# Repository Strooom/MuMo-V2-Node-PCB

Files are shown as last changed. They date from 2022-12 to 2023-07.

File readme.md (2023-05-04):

# Lora-based environmental monitor
* intended for monitoring collection items in musea. Other applications are possible but the unit is currently designed for indoor use only
* monitors temperature, relative humidity, VOC gasses, barometric pressure, light intensity and others
	- BME680 and TSL25911 sensors are built in, other can be added through I2C or UART
* runs on a single cell LiFePO4 battery. Battery-charger from USB-C port included
* Wio-E5 LoRa module from www.seeedstudio.com. This contains an STM32WLE processor combined with Semtech SX126X radio. The firmware runs directly on the STM32. More info on this Wio-E5 :  https://www.seeedstudio.com/LoRa-E5-Wireless-Module-p-4745.html
* 128 KByte of onboard EEPROM allows to buffer sensor-readings when network is unavailable.
* ePaper display allows to identify the device, and read status from the display, while still being ultra low power.

The related firmware for this device can be found in https://github.com/Strooom/MuMo-v2-Node-SW

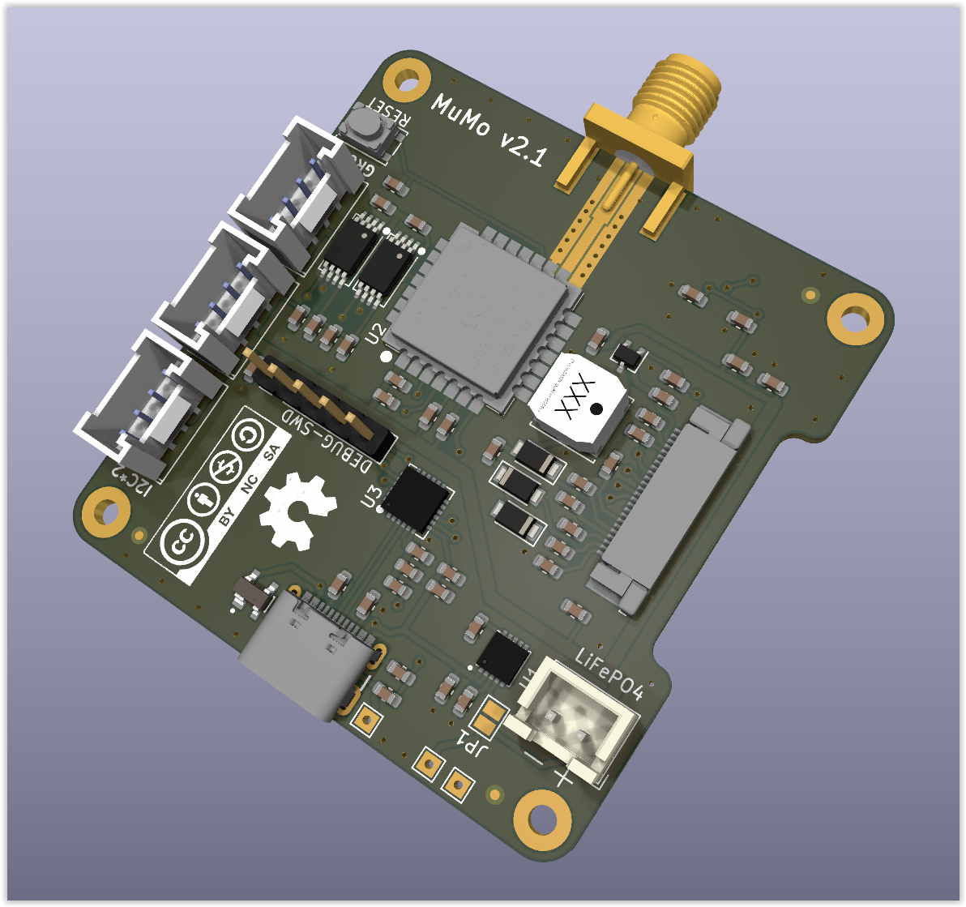
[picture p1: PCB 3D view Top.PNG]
PCB Render Top view


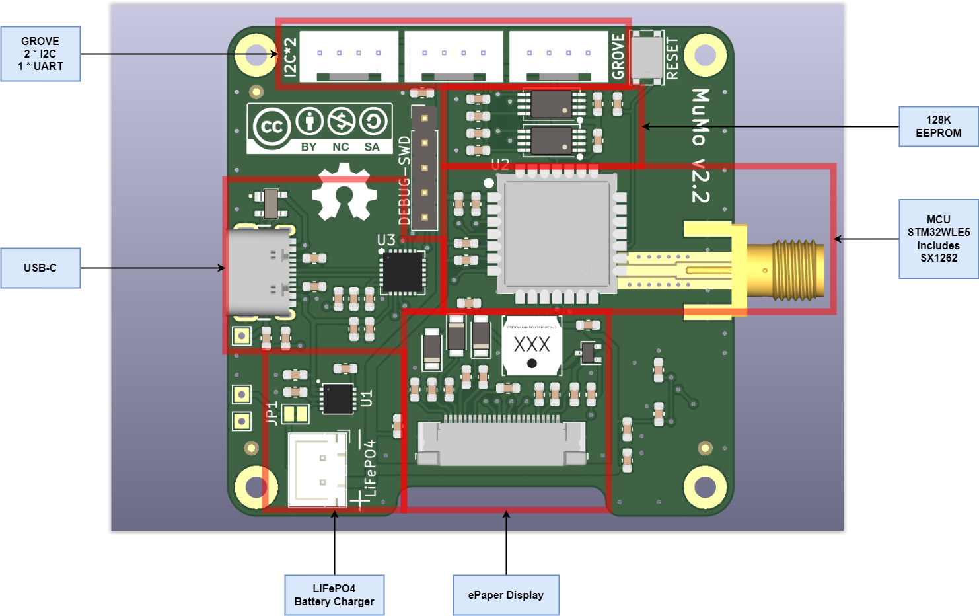
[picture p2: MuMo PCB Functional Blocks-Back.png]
PCB Backside Functional Blocks


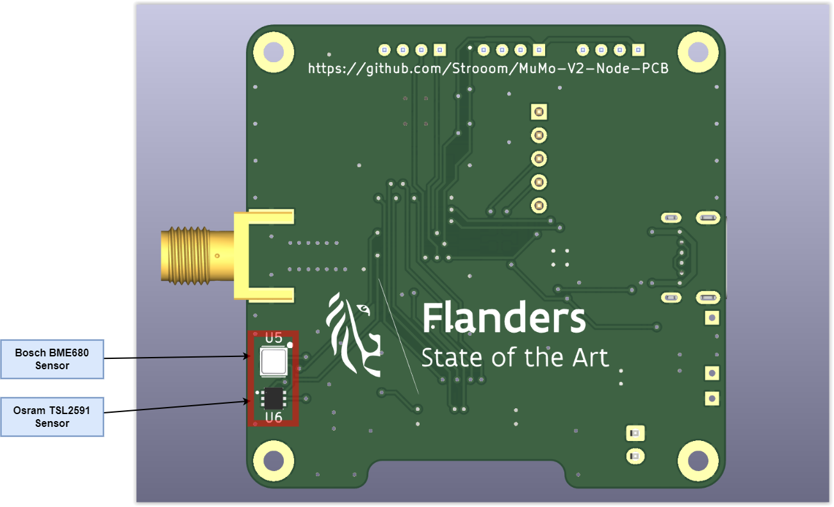
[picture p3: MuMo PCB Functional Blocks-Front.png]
PCB Frontside Functional Blocks


More info can be found in the Wiki : 
https://github.com/Strooom/MuMo-V2-Node-PCB/wiki

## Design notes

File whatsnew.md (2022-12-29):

# Improvements MuMo V2 HW vs V1

1. has a USB-C connector (io. USB-micro) which is the new EU standard for charging devices
2. has a USB-UART chip (CN2102N) so the USB connection with any PC-host will stay alive. V1 loses the connection after going into low-power-sleep
3. has a built-in charger for LiFePO4 battery. The MCU is aware of external USB-power and can adjust its program flow on it.
4. has the 2 most common sensors (BME68x and TSL2591/TSL2561) built in, and still 2 Grove-I2C and 1 Grove-UART connector, for extending to additional sensors
5. runs the SW on the embedded STM32WLE5 MCU, reducing size, power and cost. V1 used an ATSAMD21 MCU which is currently out of stock.
6. has EEPROM on the PCB to store:
    - all network settings. V1 requires a unique firmware per device. V2 firmware will be standard and use unique settings from EEPROM
    - all data until confirmed by the cloud application
    - V1 stored settings in the MCU flash, but this flash has a limited number of erase/write cycles (10K io. 10M)
7. has a better antenna connector (SMA), resulting in better radio signal, lower power, more bandwidth, etc. Different antennas exist for this connector
8. has an ePaper display. This display will improve the human interaction with the device:
    - show the device's identity
    - show the battery level
    - show charging progress
    - show network connectivity
    - show any kind of alarms, measurement values, etc
9. can be programmed and debugger via SWD connector with standard ST-LINK - Programming via USB is also foreseen 

# Improvements Descoped for this iteration, candidates for a next iteration
* could use a PCB antenna. This would require to also add an RF switch.

# Removed from the design
* Real-time clock (RTC) : I did no longer see the benefits vs the built-in RTC in the STM32, given that we can regularly sync its clock from the LoRa network.

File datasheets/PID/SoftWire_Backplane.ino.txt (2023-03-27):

// *****************************************************
//
// V1.0,          Original version of SoftI2C code ... works OK but basic
// V2.0, 08/02/17 Cleaned up the code from V.1.0 - it works but was messy
// V2.1, 17/02/17 Takes Input from Serial Console for live re-configuration
//                Also counts uSecs between measures rather than ms accumulateddevice manager
// V3.0, 21/02/17 Added the RTC module, RTC & ASIC Temperature Monitoring.
// V4.0  01/05/19 DD Take over code base and rewrite
//
String Revision_Info = "Backplane V4.0 With Serial I/P & Temp";

// ******************************************************
// This program uses the Soft I2C library because The standard Wire library does
// not work with  the I2C protocol. Soft wire I2C library is available from:
// https://github.com/felias-fogg/SoftI2CMaster
// NB setClock() prototype needs to be commented out in line 56 of file SoftWire.h
// to remove compiler warning.
// 
// Pinout of Breakout Board header (PYB-266)
// ================================================
//                               /----+
// Vdd 3.3V MAX, NOT 5V       1 | o o | 2  Unassigned
// SCL (12C)Digital I/O       3 | o o | 4  SDA (12C)Digital I/O
// CS needs start-up sequence 5  ]o o | 6  INT (Optional)
// SYNC (Optional)            7 | o o | 8  CLK (Optional)
// Unassigned                 9 | o o | 10 Gnd
//                              +-----+
//
// Sensor to MCU interface board Pinout
// =====================================================
//   PYB-269 Left           Nano        PYB-269 Right
//  ----------------------  ----------- -------------------------
//  Rev B,diff Rev A        Left  Right Rev A         Rev B,diff
//  ---------  -----------  ----  ----- --------      -----------
//  N/C        INT_Sensor_2 TX1   VIN   VIN 
//  N/C        INT_Sensor_3 RX0   GND   GND all sensors
//             N/C          RST   RST   N/C
//             N/C          GND   5.0v  N/C
//             BT_2         D2    A7    INT_Sensor_4  N/C
//             Emit_Sync    D3    A6    BT_5          INT_Sensor_4
//             SDA          D4    A5    BT_4          INT_Sensor_3
//             SCL          D5    A4    BT_3          INT_Sensor_2
//             CS_1         D6    A3    INT_Sensor_1
//             Sync_microC  D7    A2    N/C
//             CLK_microC   D8    A1    LED_Ready
//             BT_0         D9    A0    LED_Running
//             BT_1         D10   REF   N/C
//             CS_2         D11   3.3v  VDD all sensors
//             CS_3         D12   D13   CS_4
//
// ******************************************************
// The default Address for the SMD device is 0x65
// this is shifted 1 bit to 11001010b; LSB =0, Wr =1, Rd 
//
// There are 5 24-bit A-D's (Channels 00 - 04)
// On single pixel Sensor, data on Channel 2
// On 2 x 2 pixel Sensor, data on Channel 1-4
//
// You can also define the following I2C constants
// - I2C_FASTMODE = 1, I2C bus up to 400 kHz
// - I2C_SLOWMODE = 1, I2C bus up to 25 kHz 
// Table of I2C bus speed in kbit/sec:
// CPU clock:           1MHz   2MHz    4MHz   8MHz   16MHz   20MHz
// Fast I2C mode          40     80     150    300     400     400
// Standard I2C mode      40     80     100    100     100     100
// Slow I2C mode          25     25      25     25      25      25  

//#define DEBUG                // uncomment to switch on Debug messages
#define I2C_FASTMODE 1
//#define eP_i2c  0x65        // Sensor I2C default address
byte eP_i2c = 0x65;           // Sensor I2C default address

#include "Sensor.h"               // Include Sensor Header
//#include <Wire.h>
#include <SoftWire.h>             // Assembly is in "softI2CMaster.h", included by SoftWire.h

// Global Variables
byte eP_FIFO[EP_FIFO_SZ+1] = {0,0,0,0,0,0,0,0,0,0,0,0,0,0,0,0,0,0}; // FIFO AND I2C comms buffers 
byte eP_STATUS = 0xFF;

unsigned long time_1;             // Timing Monitoring counters
unsigned long time_2;

// Channel Data & counters
byte eP_Clk_Div = 0;
byte eP_Pixel   = 1;

byte temp_on; // flag to indicate if channel 0 is set as a temp sensor, or

// General Variables
//byte error;
byte CPU_divider ;
//float Seconds_Passed; // not used
String keyboard_buffer;

SoftWire Wire = SoftWire();         // Create the Softwire Instance

/*******************************************************************************
 * Simple LED control macros
 *******************************************************************************/
#define RUN_LED_ON   digitalWrite(EP_LED_RUN, LOW)
#define RUN_LED_OFF  digitalWrite(EP_LED_RUN, HIGH)
#define RDY_LED_ON   digitalWrite(EP_LED_RDY, LOW)
#define RDY_LED_OFF  digitalWrite(EP_LED_RDY, HIGH)

// The Sensor CS is a 3V input and the Arduino Nano o/ps are a 5V o/p,
// so to minimise the strain on the Sesnor, the CS line is only an o/p
// when driving the line low. To o/p a high, the CP o/p is switched to
// an i/p, with internal pull up 20k resistor, wich can supply
// (5V-3V)/20k= 0.1 mA. The ESD clamping dione can pass 100mA max, so 
// the clamping diode can clamp the i/p CS line with ease.
#define EZP_DSEL(CS)  digitalWrite((CS),LOW);\
                      pinMode ((CS), OUTPUT);\
                      digitalWrite ((CS),LOW);
                
#define EZP_SEL(CS) digitalWrite ((CS), 0);\
                    pinMode ((CS), INPUT_PULLUP);
//                  pinMode((CS),     OUTPUT); 
//                  digitalWrite ((CS), HIGH);
//  PORTD |=  _BV(PD6);                     // toggle CS_1,D6/ PD6, 38x speed of Arduino Code
//  PORTD &= ~_BV(PD6);                     // Arduino toggle is 4.75us, True C toggle is 0.125us
//  PORTD |=  _BV(PD6);

/********************************************************************************
 * Setup function
 ********************************************************************************/
void setup(void) {
  time_1= micros();                       // Start the timer counter
  temp_on= 1;
  // Configure the Arduino I/O to talk to the Sensor Breakout Board Backplane
  pinMode(EP_LED_RUN, OUTPUT);            // Set the "Running" LED
  pinMode(EP_LED_RDY, OUTPUT);
//  pinMode(EP_CS1,     OUTPUT);            // Chip Selects for the 4 possible Sensors
//  pinMode(EP_CS2,     OUTPUT);            //
//  pinMode(EP_CS3,     OUTPUT);            // 
//  pinMode(EP_CS4,     OUTPUT);            // 
  pinMode(A2,         OUTPUT);            // Softserial port Tx line
  
  pinMode(EP_INT1,    INPUT_PULLUP);      // Interrupt (INT) is on A3
    
//  digitalWrite(EP_CS1, HIGH);             // Ensable all Chip Selects
//  digitalWrite(EP_CS2, HIGH);             // 
//  digitalWrite(EP_CS3, HIGH);             // 
//  digitalWrite(EP_CS4, HIGH);             // 
//    while(1){}
EZP_SEL(EP_CS1)
EZP_DSEL(EP_CS1)
EZP_SEL(EP_CS1)
EZP_SEL(EP_CS2)
EZP_SEL(EP_CS3)
EZP_SEL(EP_CS4)

  Wire.begin();                           // Start up the Soft i2c bus

  RUN_LED_OFF;
  RDY_LED_OFF;

  // Chip Sellect Start-up Scenario - CS toggling.
  // The CS line controls both power and reset at the same time, 
  // then some of the internal register will not be reset properly. 
  // The CS sequence should be:
  //  - CS high, wait at least 5us for 1.8v regulator to come up
  //  - CS low, wait 0.10us - 10us. The low pulse can be as short as 0.05us. 
  //    If CS low >100us (~155us) the power supply will drop. 
  //    Then restart the sequence again.
  //  - CS high to complete the reset.

  time_2 = micros();
  while(micros() - time_2 < 10){}  // Force 10 us Hi to ensure stable start - Have gone as low as 5us and still OK
  
  // Force the smallest possible Low (Lo/Hi on Chip Select) for stable reset
  // these are the timings for the Arduino digitalWrite toggle
  // Div 2^0 @ 16MHz   = 4.122us - Pass (76,800 baud)
  // Div 2^1 @  8MHz   = 8.375us - Pass (38,400 baud)
  // Div 2^2 @  4MHz   = 16.75us - Pass (19,200 baud)
  // Div 2^3 @  2MHz   = 33.5us  - Pass ( 9,600 baud)
  // Div 2^4 @  1MHz   = 67.0us  - Pass ( 4,800 baud)
  // Div 2^5 @ 500kHz  = 134us   - Pass ( 2,400 baud)
  // Div 2^6 @ 250kHz  = 268us   - Fail ( 1,200 baud)
  // Div 2^7 @ 125kHz  = 536us   - Fail (   600 baud)
  // Div 2^8 @ 67.5kHz = 1072us  - Fail (   300 baud)

  // Force the smallest possible Low (Lo/Hi on Chip Select) for stable rst ... 
  // these are the timings for the True C toggle
  // Div 2^0 @ 16MHz  = 0.125us  - Pass (76,800 baud)
  // Div 2^1 @ 8MHz    = 0.250us - Pass (38,400 baud)
  // Div 2^2 @ 4MHz    = 0.500us - Pass (19,200 baud)
  // Div 2^3 @ 2MHz    = 1.0us   - Pass ( 9,600 baud)
  // Div 2^4 @ 1 MHz   = 2.0us   - Pass ( 4,800 baud)
  // Div 2^5 @ 500kHz  = 4.0us   - Pass ( 2,400 baud)
  // Div 2^6 @ 250kHz  = 8.0us   - Pass ( 1,200 baud)
  // Div 2^7 @ 125kHz  = 16.0us  - Pass (   600 baud)
  // Div 2^8 @ 67.5kHz = 32.0us  - Pass (   300 baud)
//    while(1){}
  PORTD |=  _BV(PD6);                     // toggle CS_1,D6/ PD6, 38x speed of Arduino Code
  PORTD &= ~_BV(PD6);                     // Arduino toggle is 4.75us, True C toggle is 0.125us
  PORTD |=  _BV(PD6);
//    while(1){}
  // adjusting the AVR CPU speed
  CLKPR = 0x80;                           // Tell the AtMega we want to change the system clock
  CLKPR = 0x00;                           // eg 2^5= 1/32 prescaler= 0.5MHz for a 16MHz crystal
  CPU_divider = 1;                        // for(i=0 ; i< 0 ; i++){CPU_divider = CPU_divider * 2;}
  
  Serial.begin(115200);                   // NB With 1/32 clk (2^5), console is 2,400(0.5 MHz)
#ifdef DEBUG
  Serial.println(F("1Debugging Enabled"));
#endif
  RUN_LED_ON;
  Serial.println(); Serial.println(); Serial.println();
  Serial.println(Revision_Info);
  Serial.println(F("============================================================"));
  Serial.println();
  Start_ASIC();

  printTitleBar();
  RUN_LED_OFF;
} // End of Set Up

/*********************************************************************************
 * Main loop function
 *********************************************************************************/
void loop(void){
  byte OR_Flags   = 0;                    // Byte used to store ch0-ch4 OR in bits 0-4
  unsigned long channel_0;
  unsigned long channel_1;
  unsigned long channel_2;
  unsigned long channel_3;
  unsigned long channel_4;
  //unsigned long channel_sign;
  unsigned int frame_count;
  float channel_Temperature=0;
  static unsigned long dataLine = 0;      // Line count of output data

#ifdef DEBUG
  Serial.print(F("1Loop count: "));
  Serial.println(dataLine);
#endif
  while (Serial.available() > 0) {        // Check for Serial Input
#ifdef DEBUG
  Serial.print(F("1Avail= ")); 
  Serial.println(Serial.available());
  Serial.println(F("1data in i/p buffer"));
#endif
    keyboard_buffer= Serial.readString(); // Read the keyboard string
    keyboard_buffer= capsFilterInput(keyboard_buffer);
//    dumpString(keyboard_buffer);
#ifdef DEBUG
    Serial.print(F("1Buff1= ")); Serial.println(keyboard_buffer);
#endif
//while(1){};  while (Serial.available()==0) {} 

  processCommand();

//  Serial.println("Hit 'Enter' to continue");
//  while (Serial.available()==0) {} 
//  Serial.readString();
#ifdef DEBUG
    Serial.print(F("1Buff2= "));   Serial.println(keyboard_buffer);
    Serial.print(F("1temp_on= ")); Serial.println(temp_on);
#endif
  }
  // *****************************************************************************
  // Read part of the FIFO & speed things up ? 
  // (fastest read cycle is 7.42 ms ... sould be able to get to 1ms)
  // Make a new Version (4.0 ?) for this using FIFO_READ_ACTIVE.
  //
  // FIFO_READ_ACTIVE
  // e.g. if 2 Active Channels (0 & 2) , 8 bytes.
  // Byte 0 = channel 0 bits 23:16
  // Byte 1 = channel 0 bits 15:8
  // Byte 2 = channel 0 bits 7:0
  // Byte 3 = channel 2 bits 23:16
  // Byte 4 = channel 2 bits 15:8
  // Byte 5 = channel 2 bits 7:0
  // Byte 6 = frame count MSB
  // Byte 7 = frame count LSB
  // *****************************************************************************
  RUN_LED_OFF;
  // Read the Full 17 byte FIFO
  eP_cmd_FIFO_read_full(eP_i2c);  //, eP_FIFO[0]);{
  /* ****** FIFO Structure
  FIFO_DPF  Data
  Channel 0:   Byte 0, bits 23-16  Byte 1, bits 15-8  Byte 2, bits 7-0
  Channel 1:   Byte 3, bits 23-16  Byte 4, bits 15-8  Byte 5, bits 7-0
  channel 2:   Byte 6, bits 23-16  Byte 7, bits 15-8  Byte 8, bits 7-0
  channel 3:   Byte 9, bits 23-16  Byte 10,bits 15-8  Byte 11,bits 7-0
  channel 4:   Byte 12, bits 23-16 Byte 13,bits 15-8  Byte 14,bits 7-0
  Frame Count: Byte 15,MSB         Byte 16,LSB
  */

//  OR_Flags=0;
  if(temp_on){                                                // Temp or Dark Pixel
    channel_0 = buildChReading (&eP_FIFO[EP_FIFO_CH0]);       // Channel 0, 3 bytes
    channel_Temperature = -0.026 * channel_0 + 422;    
#ifdef DEBUG
    Serial.print(F("1Tp0 Bytes: "));
#endif  
  } else {
    channel_0= buildChReading (&eP_FIFO[EP_FIFO_CH0])/ eP_Clk_Div;            // Channel 0, 3 bytes
//    OR_Flags = ((EP_OR_MSK& eP_FIFO[EP_FIFO_CH0])>>(7-EP_OR_CH0));        // OR Flag shifted into bit posn, clr other bits
#ifdef DEBUG
    Serial.print(F("1Ch0 Bytes: "));
#endif
  }

#ifdef DEBUG
    Serial.print(eP_FIFO[EP_FIFO_CH0]);
    Serial.print(F(", "));
    Serial.print(eP_FIFO[EP_FIFO_CH0+1]);
    Serial.print(F(", "));
    Serial.print(eP_FIFO[EP_FIFO_CH0+2]);
    Serial.println();
#endif

  OR_Flags = ((EP_OR_MSK& eP_FIFO[EP_FIFO_CH0])>>(7-EP_OR_CH0));        // OR Flag shifted into bit posn, clr other bits
  OR_Flags|= ((EP_OR_MSK& eP_FIFO[EP_FIFO_CH1])>>(7-EP_OR_CH1));        // Over Range Flag shifted into bit position
  OR_Flags|= ((EP_OR_MSK& eP_FIFO[EP_FIFO_CH2])>>(7-EP_OR_CH2));        // Over Range Flag shifted into bit position
  OR_Flags|= ((EP_OR_MSK& eP_FIFO[EP_FIFO_CH3])>>(7-EP_OR_CH3));        // Over Range Flag shifted into bit position
  OR_Flags|= ((EP_OR_MSK& eP_FIFO[EP_FIFO_CH4])>>(7-EP_OR_CH4));        // Over Range Flag shifted into bit position

  channel_1= buildChReading (&eP_FIFO[EP_FIFO_CH1])/ eP_Clk_Div;        // Channel 1, 3 bytes
  channel_2= buildChReading (&eP_FIFO[EP_FIFO_CH2])/ eP_Clk_Div;        // Channel 2, 3 bytes
  channel_3= buildChReading (&eP_FIFO[EP_FIFO_CH3])/ eP_Clk_Div;        // Channel 3, 3 bytes
  channel_4= buildChReading (&eP_FIFO[EP_FIFO_CH4])/ eP_Clk_Div;        // Channel 4, 3 bytes
 
  frame_count= (eP_FIFO[EP_FIFO_FC]<<8)|eP_FIFO[EP_FIFO_FC+1];          // Frame Count, 2 bytes

  // Display the data. It takes ~0.15ms / line to print to screen
  Serial.print(F(" "));
  Serial.print(dataLine++);        
  Serial.print(F("\t  "));
  if(temp_on){
    alignNumber((unsigned long)channel_Temperature);        // aligns to DP
    Serial.print(channel_Temperature, 3);
  } else{
    Serial.print("    ");
    alignNumber(channel_0);
    Serial.print(channel_0);
  }
  Serial.print(F("\t"));
  alignNumber(channel_1);
  Serial.print(channel_1);
  Serial.print(F("\t"));
  alignNumber(channel_2);
  Serial.print(channel_2);
  Serial.print(F("\t"));
  alignNumber(channel_3);
  Serial.print(channel_3);
  Serial.print(F("\t"));
  alignNumber(channel_4); 
  Serial.print(channel_4);
  Serial.print(F("\t      "));
  alignNumber((unsigned long)frame_count);
  Serial.print(frame_count);
  Serial.print(F("\t     "));
  time_2 = micros();
  alignNumber((unsigned int)((time_2 - time_1) * CPU_divider));
  Serial.print((time_2 - time_1) * CPU_divider);
  time_1 = micros();
//  if (OR_Flags){
//    Serial.println(F("\tOver Range"));
//  } else{
//    Serial.println(F("\tOK"));
//  }
  Serial.print(F("\t"));
  printHexByte (OR_Flags);
  Serial.println();
  if (!writeI2C(eP_i2c, EP_FIFO_RST, 0)) {        // Rst Full FIFO 
    Serial.println(F("Reset FIFO Error"));        // for next data set
    while (1);
  }
  RUN_LED_OFF;  
}         // End of Main Loop **************************************************************

/*********************************************************************************
 * Function printHexByte
 * Print a byte, b with a leading 0x and a leading 0 if the number to be printed 
 * is a single digit.
 *********************************************************************************/
void printHexByte(byte b){
  Serial.print (F("0x"));
  if (b<0xA){ Serial.print (F("0")); }
  Serial.print (b, HEX);
}

/*********************************************************************************
 * Function printTitleBar
 *********************************************************************************/
void printTitleBar(void){
  #ifdef DEBUG
  Serial.println(F("\tT\tT\tT\tT\tT\tT\tT\tT\tT\tT\tT\tT\tT\tT\tT"));      // Aid to aligning tab stops
  #endif
  Serial.print(F("#\sensor Temp\tSen 1\tSen 2\tSen 3\tSen 4\tFrame Count\tT Delta/uS\tOver Range"));
  Serial.println();
  Serial.print(F("=================================================================================================="));
  Serial.println();
}

/*********************************************************************************
 * Function processCommand
 * This routine acts upon the keyboard input
 *********************************************************************************/
void processCommand(void){
  static char fullReset=0;              // ASIC is started in startup function
  
  if (keyboard_buffer == "GO"){         // Config & Start ASIC
    Serial.println(F("Go received"));
    Start_ASIC();
    fullReset=0;                        // Enable commands, once ASIC has been started

    Serial.println(F("Sensor Started ..."));
    printTitleBar();
  }
  if (0==fullReset){                        // Disable commands, until ASIC has been started

    eP_cmd_FIFO_read_full(eP_i2c);      //, ep_FIFO[0]);
    if (keyboard_buffer == "P"){    // Pause the serial port until any keypress 
      while (!Serial.available()){}
//    keyboard_buffer = Serial.readString();         
    }
    
    if (keyboard_buffer == "CLR"){              // Clr & Rst serial comms- only works on terminal, not Arduino monitor ...
      Serial.write(27);                         // ESC
      Serial.print(F("[2J"));                   // clear screen
      Serial.write(27);                         // ESC
      Serial.print(F("[H"));                    // cursor home
      Serial.println(F("Serial Reset ..."));  
    }
    if (keyboard_buffer == "RST F"){            // Full Reset the ASIC
      if (!writeI2C(eP_i2c, EP_RST_FULL, 0)) { // Send a full Reset
        Serial.println(F("Write Full Reset Error"));
        while (1);
      }
      fullReset=1;                                // Disable commands, until ASIC has been restarted
      Serial.println(F("Full Reset ..."));  
    }

    if (keyboard_buffer == "RST S"){                    // Soft Reset the ASIC
      if (!writeI2C(eP_i2c, EP_RST_SFT, 0)){ // Send a Soft Reset
        Serial.println(F("Write Soft Reset Error"));
        while (1);
      }
      Serial.println(F("Soft Reset ..."));  
    }

/*********************************************************************************
 * Analog Front End Modification
 * *******************************************************************************/
  if (keyboard_buffer== "TEMP ON") {                  // Set the Temperature Monitoring On
    configAFE (EP_AFE1_TMP_MSK, EP_AFE1_TMP_EN, "Temperature Monitoring On");
  }
  if (keyboard_buffer== "TEMP OFF") {                 // Temp Monitoring Off
    configAFE (EP_AFE1_TMP_MSK, EP_AFE1_TMP_DIS,"Temperature Monitoring Off");
  }
    
    if (keyboard_buffer.charAt(0) == 'S'){              // set the sample rate  
      Serial.print(F("Clock Divider was = "));
      Serial.println(eP_Clk_Div);      
      keyboard_buffer.remove(0, 1);                     // Remove the 'S'
      eP_Clk_Div = keyboard_buffer.toInt();             // Convert String to Int
      Serial.print(F("Clock Divider is now = "));
      Serial.println(eP_Clk_Div);
      Read_AFE();                                       // Read Analogue Front End 
      eP_FIFO[0] = (eP_Clk_Div - 1);                    // set the sample rate        
      Write_AFE();                                      // Write Analogue Front End 
      Serial.println(F("Sample Rate Set"));
      Read_AFE();                                       // Read Analogue Front End 
    } // End If "Sample Rate"

    if (keyboard_buffer == "HPF ON") {                  // Enable High Pass Filter  
      configAFE (EP_AFE1_HIPASS_FLTR_MSK, EP_AFE1_HIPASS_FLTR_EN, "High Pass Frequency Filter Enabled");
    }
    if (keyboard_buffer == "HPF OFF") {                 // Disable High Pass Filter
       configAFE (EP_AFE1_HIPASS_FLTR_MSK, EP_AFE1_HIPASS_FLTR_DIS, "High Pass Frequency Filter Disabled");
    }

    if (keyboard_buffer == "PWR LO") {                // Sensor Low Power Mode  
      configAFE (EP_AFE1_LO_POW_MSK, EP_AFE1_LO_POW_EN, "Low Power Mode Enabled");
    }
    if (keyboard_buffer == "PWR HI") {                // Sensor Standard (High) Power Mode  
      configAFE (EP_AFE1_LO_POW_MSK, EP_AFE1_LO_POW_DIS, "Low Power Mode Disabled");
    }

    if (keyboard_buffer == "LPF22.5") {               // Set LPF Freq to 22.5Hz
      configAFE (EP_AFE1_LOPASS_MSK, EP_AFE1_LOPASS_FRQ_022_5, "Low Pass Frequency Filter set to 22.5Hz");
    }
    if (keyboard_buffer == "LPF45") {                 // Set LPF Freq to 45Hz
      configAFE (EP_AFE1_LOPASS_MSK, EP_AFE1_LOPASS_FRQ_045, "Low Pass Frequency Filter set to 45Hz"); 
    }
    if (keyboard_buffer == "LPF90") {                 // Set LPF Freq to 90Hz
      configAFE (EP_AFE1_LOPASS_MSK, EP_AFE1_LOPASS_FRQ_090, "Low Pass Frequency Filter set to 90Hz");
    }
    if (keyboard_buffer == "LPF180") {                // Set LPF Freq to 180Hz
      configAFE (EP_AFE1_LOPASS_MSK, EP_AFE1_LOPASS_FRQ_180, "Low Pass Frequency Filter set to 180Hz");
    }

/*********************************************************************************
 * Channel Control Packet (CCP) Modification 
 *********************************************************************************/
    if (keyboard_buffer == "PX1") {                   // Single Pixel Sensor
      eP_Pixel= 1;
      Read_CCP();                                     // Read the CCP
      set_CCP();
      Write_CCP();                                    // Write CCP
      Serial.println(F("Single Pixel Sensor Set"));
      Read_CCP();                                     // Read the CCP
    }

    if (keyboard_buffer == "PX4") {                   // 2x2 Pixel Sensor
      eP_Pixel= 4;
      Read_CCP();                                     // Read the CCP
      set_CCP();
      Write_CCP();                                    // Write CCP
      Serial.println(F(" 2x2 Pixel Sensor Set"));
      Read_CCP();                                     // Read the CCP
    }

    if (keyboard_buffer == "HPF1") {
      configCCP (EP_CCP_HPF_MSK, EP_CCP_HP_FLTR1, "High Pass Frequency Filter set to 1Hz");
    }
    if (keyboard_buffer == "HPF2") {
      configCCP (EP_CCP_HPF_MSK, EP_CCP_HP_FLTR2, "High Pass Frequency Filter set to 2Hz");
    }
    if (keyboard_buffer == "HPF4") {
      configCCP (EP_CCP_HPF_MSK, EP_CCP_HP_FLTR4, "High Pass Frequency Filter set to 4Hz");
    }
    if (keyboard_buffer == "HPF8") {
      configCCP (EP_CCP_HPF_MSK, EP_CCP_HP_FLTR8, "High Pass Frequency Filter set to 8Hz");
    }
 
    if (keyboard_buffer == "T120") {
      configCCP (EP_CCP_TRNS_MSK, EP_CCP_TRNS_120T, "Transconductance set to 1.2T");
    }
    if (keyboard_buffer == "T060") {
      configCCP (EP_CCP_TRNS_MSK, EP_CCP_TRNS_060T, "Transconductance set to 0.6T");
    }
    if (keyboard_buffer == "T030") {
      configCCP (EP_CCP_TRNS_MSK, EP_CCP_TRNS_030T, "Transconductance set to 0.3T");
    }
    if (keyboard_buffer == "T015") {
      configCCP (EP_CCP_TRNS_MSK, EP_CCP_TRNS_015T, "Transconductance set to 0.15T");
    }
    
    if (keyboard_buffer == "X1"){
      configCCP (EP_CCP_AMP_MSK, EP_CCP_AMP_01X, "Amplification set to 1x");
    }
    if (keyboard_buffer == "X2"){
      configCCP (EP_CCP_AMP_MSK, EP_CCP_AMP_02X, "Amplification set to 2x");
    }
    if (keyboard_buffer == "X4"){
      configCCP (EP_CCP_AMP_MSK, EP_CCP_AMP_04X, "Amplification set to 4x");
    }
    if (keyboard_buffer == "X8"){
      configCCP (EP_CCP_AMP_MSK, EP_CCP_AMP_08X, "Amplification set to 8x");
    }
    if (keyboard_buffer == "X16"){
      configCCP (EP_CCP_AMP_MSK, EP_CCP_AMP_16X, "Amplification set to 16x");
    }
    if (keyboard_buffer == "X32"){
      configCCP (EP_CCP_AMP_MSK, EP_CCP_AMP_32X, "Amplification set to 32x");
    }
    if (keyboard_buffer == "X64"){
      configCCP (EP_CCP_AMP_MSK, EP_CCP_AMP_64X, "Amplification set to 64x");
    }
  }
  keyboard_buffer ="";
} // End Serial Port Read
    
void configAFE (uint8_t mask, uint8_t setBits, String msg){
  Read_AFE();                                    // Read the CCP
  eP_FIFO[1]&= mask;
  eP_FIFO[1]|= setBits;
  Write_AFE();                                   // Write CCP
  Serial.println(msg);
  Read_AFE();                                    // Read the CCP
//  Serial.println ("Hit Enter to continue");
//  while (Serial.available()==0) {} 
}
void configCCP (uint8_t mask, uint8_t setBits, String msg){
  Read_CCP();                                    // Read the CCP
  eP_FIFO[2]&= mask;
  eP_FIFO[2]|= setBits;
  set_CCP();
  Write_CCP();                                   // Write CCP
  Serial.println(msg);
  Read_CCP();                                    // Read the CCP
//  Serial.println ("Hit Enter to continue");
//  while (Serial.available()==0) {} 
}
/*********************************************************************************
 * Function Start_ASIC function
 * Setup & Start the ASIC
**********************************************************************************/
void Start_ASIC(void) {
  byte errorCode, ver;

  Serial.print(F("Starting ASIC: "));
  errorCode= eP_cmd_start_I2C (eP_i2c);
  check_error(errorCode);

  ver= eP_cmd_rd_ver(eP_i2c);
  Serial.print(F("ASIC Version= "));
  printHexByte(ver);
  Serial.println();
  // ***** Write the Analog Front End Packet 
  // Byte 0 is the Sampling Rate. Sample Rate= 1000/ (N+ 1)
  // N= 0, Rate= 1000.00; N= 255, Rate= 3.91
  // Note that when you use this, the number of readings (N+1) get added together
  // so the full 23 bits of the data packet get used ... 
  eP_Clk_Div = 10;
  eP_FIFO[0] = (eP_Clk_Div - 1);
  // Set AFE Byte 1
  eP_FIFO[1]=  EP_AFE1_INT_EN| EP_AFE1_TMP_EN| EP_AFE1_LOPASS_FRQ_022_5| EP_AFE1_HIPASS_FLTR_EN;  // En Interrupts, En Temp, LPF, HPF on
  
  Write_AFE();                                      // Write AFE
  Read_AFE();                                       // Read AFE
  
  // ***** Write the Channel Control Packet
  // Set up CCP
  // Activate Channel 2
  eP_FIFO[2]|= EP_CCP_EN;
  eP_FIFO[2]|= EP_CCP_TRNS_015T;                    // Transcond 0.15T
  eP_FIFO[2]|= EP_CCP_HP_FLTR8;                     // Set HPF to 8 Hz

  if(eP_Pixel == 1){
    eP_FIFO[2]|= EP_CCP_AMP_01X ;                   // Fb Cap 3200= 1x Amp
    eP_FIFO[0]= eP_FIFO[2];                         // Ch0 is temp- Activate ch
  } else{
    eP_FIFO[2]|= EP_CCP_AMP_16X ;  
    eP_FIFO[0]= eP_FIFO[2];                         // Ch0 is temp- Activate ch
    eP_FIFO[1]= eP_FIFO[2];                         // Channel 1 Activated 
    eP_FIFO[3]= eP_FIFO[2];                         // Channel 3 Activated
    eP_FIFO[4]= eP_FIFO[2];                         // Channel 4 Activated
  }
  
  set_CCP();
  Write_CCP();                                      // Write CCP
  Read_CCP();                                       // Read CCP

  eP_i2c= cP_cmd_set_I2C_addr(eP_i2c, 0x65);      //, eP_FIFO[0]);
  Serial.print(F("I2C Addr set to = 0x"));
  Serial.println(eP_i2c, HEX);

  if (!writeI2C(eP_i2c, EP_FIFO_RST, 0)) {            // Reset the full FIFO
    Serial.println(F("Reset FIFO Error"));
    while (1);
  }
  Serial.println();
}

//################################# I2C: basic I2C ###############################
/*********************************************************************************
 * readI2C function
 * Standard READ routine
 *********************************************************************************/
boolean readI2C(byte addr, byte command, byte data_count) {
  byte i;
  boolean  result=true;
  Wire.beginTransmission(addr);
  Wire.write(command);
  if (Wire.endTransmission(false) != 0) result= false;
  Wire.requestFrom(eP_i2c, data_count);
  for (i = 0 ; i < data_count ; i++){
    eP_FIFO[i] = Wire.read();
  }
  return result;
} // End of Read I2C

/*********************************************************************************
 * function
 * Standard WRITE routine
 *********************************************************************************/
boolean writeI2C(byte addr, byte command, byte data_count) {
  byte i;
  Wire.beginTransmission(addr);
  Wire.write(command);
  for (i = 0 ; i < data_count ; i++){
    Wire.write(eP_FIFO[i]);
  }
  return true;
} // End of Write I2C

/*********************************************************************************
 * Function set_CCP
 * Set the CCP depending on single or 2x2 sensor
 * Activate Channel 1 , 2, 3 , 4 (4-pixel device)
 *********************************************************************************/
void set_CCP(){
  eP_FIFO[0] = eP_FIFO[2];
  eP_FIFO[1] = eP_FIFO[2];
  eP_FIFO[3] = eP_FIFO[2];
  eP_FIFO[4] = eP_FIFO[2];

  if(eP_Pixel != 4){  
    eP_FIFO[1]&= ~EP_CCP_EN;
    eP_FIFO[3]&= ~EP_CCP_EN;
    eP_FIFO[4]&= ~EP_CCP_EN;
  }
} // End of Set CCP

//################################# eP_cmd: Sensor commands ######################

/*********************************************************************************
 * Function 
 * Start I2C bus and test for presence of device
**********************************************************************************/
byte eP_cmd_start_I2C (byte addr){
  byte result;
  
  Wire.beginTransmission(addr);                           // Check the device is on the i2C bus at 0x65
  result = Wire.endTransmission();
  return result;
}

/*********************************************************************************
 * Function read version number
 * Get the version number of the ezPyro ASIC
**********************************************************************************/
  byte eP_cmd_rd_ver (byte addr){
    if (!readI2C(addr, EP_VER, 1)) {                // Read the chip Version 
      Serial.println(F("Read Version Error"));
      while (1);
    }
    return eP_FIFO[0];
  }

/*********************************************************************************
 * Function set I2C address
 * set the I2C address to a new address
**********************************************************************************/
byte cP_cmd_set_I2C_addr( byte addr, byte new_addr){
//, byte *buff){
//  buff= new_addr<< 1;                             // Shift 7 LSB to 7 MSB
  eP_FIFO[0]= new_addr<<1;
  if (!writeI2C(addr, EP_ADDR_WR, 1)) {           // Change the Address 
    Serial.println(F("Write Set Addr Error"));
    while (1);
  }
  return new_addr;
}

/*********************************************************************************
 * Function eP_cmd_FIFO_reaed_full
 * read a full 17 bytes from the ezPyro's ASIC's FIFO
 *********************************************************************************/
void eP_cmd_FIFO_read_full (byte addr){   //, byte *buff) {
  while(!readI2C(addr, EP_FIFO_RD_FULL, EP_FIFO_SZ)){}    // Loop til Sensor is ready to take cmd
}

/*********************************************************************************
 * Function check_error
 * Error Codes from I2C bus communication
 * byte, which indicates the status of the transmission:
 * 0: success
 * 1: data too long to fit in transmit buffer
 * 2: received NACK on transmit of address
 * 3: received NACK on transmit of data
 * 4: other error
 *********************************************************************************/
void check_error(byte error){
  Serial.println();
  if (error== ERR_OK) {
//    Serial.print(F("Good Tx")); // 'F' puts string in flash 
  } else if (error== ERR_LON_DATA) {
    Serial.print(F("Data too long to fit in tx buffer"));
  } else if (error== ERR_NAK_ADDR) {
    Serial.print(F("Rxed NACK on tx of addr"));
  } else if (error== ERR_NAK_DATA) {
    Serial.print(F("Rxed NACK on tx of data"));
  } else if (error== ERR_UNKNOWN){
    Serial.print(F("Unknown error1"));
  } else{
    Serial.print(F("Unknown error2- "));
    Serial.print(error);
  }
  if (error!= ERR_OK) {
    PRINT2HEX (" at addr 0x", eP_i2c); // Print address, if there is an error
  }
} // End of Error Checking

/*********************************************************************************
 * Function Read_AFE
 * AFE= Analogue Front End
 *********************************************************************************/
void Read_AFE(void) {
  byte i;
  if (!readI2C(eP_i2c, EP_AFE_RD, EP_AFE_SZ)) {     // Read AFE
    Serial.println(F("Read AFE Error"));
    while (1);
  }
  Serial.print(F("AFE= "));               // Print out the contents of the AFE
  for (i= 0; i< EP_AFE_SZ; i++){
    if (i!=0) {Serial.print(F(", "));}    // No comma before the 1st number
    printHexByte(eP_FIFO[i]);
  }
  Serial.println();  
}

/*********************************************************************************
 * Function Write_AFE
 *********************************************************************************/
void Write_AFE(void){
  if (!writeI2C(eP_i2c, EP_AFE_WR, EP_AFE_SZ)) {   // Write AFE
    Serial.println(F("Write AFE Error"));
    while (1);
  }
}

/*********************************************************************************
 * Function Read_CCP
 * CCP= Channel Control Packet
 *********************************************************************************/
void Read_CCP(void){
  byte i;
  if (!readI2C(eP_i2c, EP_CCP_RD, EP_CCP_SZ)) {   // Read the CCP 
    Serial.println(F("Read CCP Error"));
    while (1);
  }
  Serial.print(F("CCP= "));               // Print out the contents of the CCP
  for (i= 0; i< EP_CCP_SZ; i++){
    if (i!=0){ Serial.print(F(", "));}    // No comma before the 1st number
     printHexByte(eP_FIFO[i]);
  }
  Serial.println();
}

/*********************************************************************************
 * Function Write_CCP
 *********************************************************************************/
void Write_CCP(void){
  if (!writeI2C(eP_i2c, EP_CCP_WR, EP_CCP_SZ)) { // Write the CCP
    Serial.println(F("Write CCP Error"));
    while (1);
  }
}

/*********************************************************************************
 * Function Write_block
 *********************************************************************************/
/*boolean writeBlock(Addr, Buffer, ByteCount){
  boolean result=true;
  if (!writeI2C(Addr, Buffer, ByteCount)) result=false;}
  return result;
}
*/

/*********************************************************************************
 * Function Align Number
 * padds spaces, so numbers are decimal point aligned. up to 99,999.
 *********************************************************************************/
void alignNumber(unsigned long num2align){
  unsigned long int iloop;
  if (num2align==0) {num2align=1;}
  for (iloop=num2align; iloop < 10000; iloop=iloop*10){
    Serial.print(F(" "));
  }
}

/*********************************************************************************
 * Function buildChReading
 * build thereading from the 3 bytes in the FIFO array
 *********************************************************************************/
unsigned long buildChReading (byte *currentByte){
  return (((unsigned long)(0x7f&(*currentByte))  <<16)|
          ((unsigned long)      (*(currentByte+1))<<8)|
          ((unsigned long)      (*(currentByte+2)))  );
}

/*********************************************************************************************
 * Capitalise text and strip CR/LF                                                           */
String capsFilterInput(String msg){
  String op;
  
  msg.toUpperCase();              // Convert to upper case
  for (uint8_t i=0; i< msg.length(); i++){
    if((msg[i]!='\n')&& (msg[i]!='\r')&& (msg[i]!='\0')) {op+=msg[i];}
  }
  return(op);
}

/*********************************************************************************************/
void dumpString(String str){
uint8_t i;
  PRINT2("dumpStr: ", str.length());
  for(i=0;i< str.length(); i++){
    Serial.print(", "); Serial.print(str[i]);
  }
  PRINT2("\n % ",str); 
}

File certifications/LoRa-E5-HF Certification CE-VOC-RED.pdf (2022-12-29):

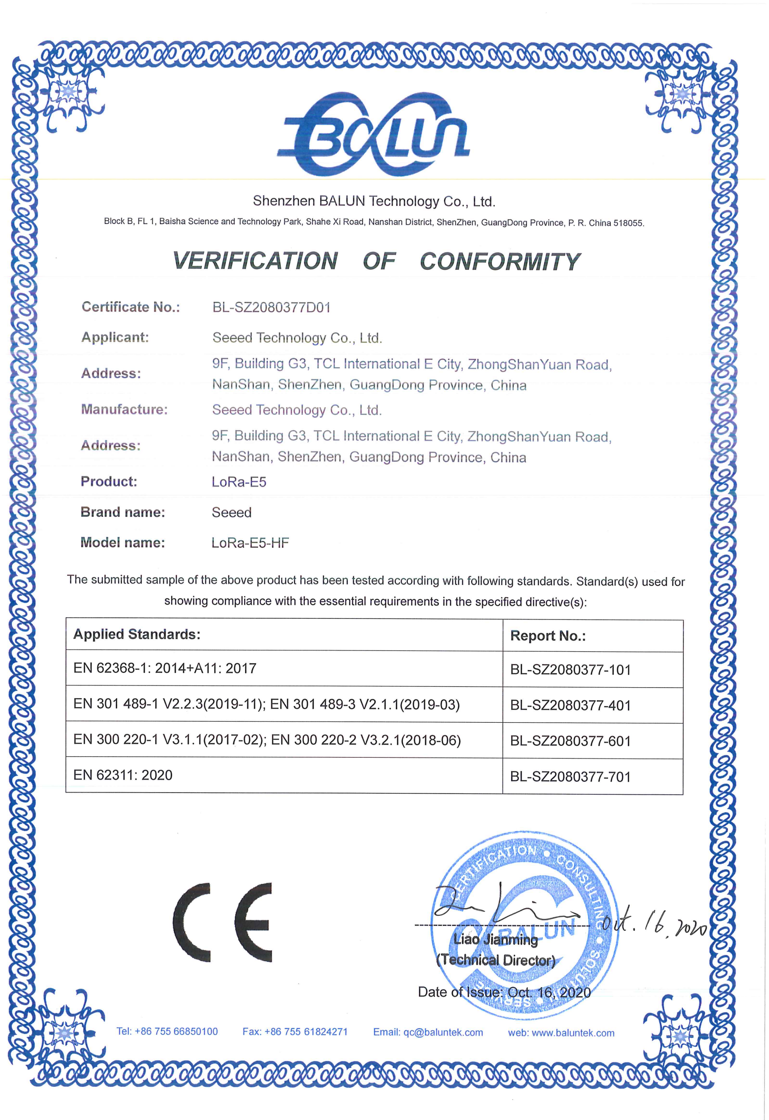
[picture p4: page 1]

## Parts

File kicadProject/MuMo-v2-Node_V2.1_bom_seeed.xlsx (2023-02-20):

Designator | MPN | Qty | Link
C1,C2,C3,C4,C5,C6,C7,C8 | CGA3E2X7R1E104K080AA | 8 | https://www.mouser.be/ProductDetail/TDK/CGA3E2X7R1E104K080AA?qs=NRhsANhppD%2Fm7%2FOmmsm0vg%3D%3D
C11,C12,C13,C14,C15,C16,C17,C18 | CGA3E1X7R1E105K080AC | 8 | https://www.mouser.be/ProductDetail/TDK/CGA3E1X7R1E105K080AC
C21,C22,C23,C24,C25,C26,C27,C28,C29,C30,C31,C32 | C1608X7S1A475K080AC | 12 | https://www.mouser.be/ProductDetail/TDK/C1608X7S1A475K080AC?qs=d72FGnIDsgRAO1hqT8K2Cw%3D%3D
C41,C42 | C1608X6S1A106M080AC | 2 | https://www.mouser.be/ProductDetail/TDK/C1608X6S1A106M080AC?qs=dfay7wIA1uH1Z78SvgoYOQ%3D%3D
CONN2 | B2B-XH-A (LF)(SN) | 1 | https://be.farnell.com/jst-japan-solderless-terminals/b2b-xh-a-lf-sn/header-vertical-2way/dp/1516276
CONN1 | 10129378-905002BLF | 1 | https://www.mouser.be/ProductDetail/Amphenol-FCI/10129378-905002BLF?qs=0lQeLiL1qyZ7vSJa38rFLQ%3D%3D
CONN5 | CONSMA020.062-G | 1 | https://www.mouser.be/ProductDetail/Linx-Technologies/CONSMA020.062-G?qs=xZ%2FP%252Ba9zWqa7zEs9%2FuMaNQ%3D%3D
CONN6 | 110990030 | 1 | https://www.mouser.be/ProductDetail/Seeed-Studio/110990030?qs=1%252B9yuXKSi8Dw9fpnq%252BdNzQ%3D%3D
CONN7 | 110990030 | 1 | https://www.mouser.be/ProductDetail/Seeed-Studio/110990030?qs=1%252B9yuXKSi8Dw9fpnq%252BdNzQ%3D%3D
CONN8 | 110990030 | 1 | https://www.mouser.be/ProductDetail/Seeed-Studio/110990030?qs=1%252B9yuXKSi8Dw9fpnq%252BdNzQ%3D%3D
CONN4 | 2171790001 | 1 | https://www.mouser.be/ProductDetail/Molex/217179-0001?qs=DRkmTr78QAQqCH4BoIR1xg%3D%3D
CONN3 | 2-1734839-4 | 1 | https://www.mouser.be/ProductDetail/TE-Connectivity/2-1734839-4?qs=Sm6ibA7evxgHWeCe9t1tOw%3D%3D
D4 | SP0503BAHTG | 1 | https://www.mouser.be/ProductDetail/Littelfuse/SP0503BAHTG?qs=uD%2FdkN7XIa0NTYXwHdELYA%3D%3D
D1,D2,D3 | SL03-GS08 SS1FL3HM3/H | 3 | https://www.mouser.be/ProductDetail/78-SS1FL3HM3-H
L1 | VLS6045EX-470M | 1 | https://www.mouser.be/ProductDetail/TDK/VLS6045EX-470M?qs=oF%2FSscNnLpBaU7vKc7Ahqw%3D%3D
Q1 | PJC7400_R1_00001 | 1 | https://www.mouser.be/ProductDetail/241-PJC7400_R1_00001
R1 | ERJ-3RQJ2R2V | 1 | https://www.mouser.be/ProductDetail/Panasonic/ERJ-3RQJ2R2V?qs=Ytx7DkVehETJPMlDNlXENw%3D%3D
R3 | CR0603-JW-102ELF | 1 | https://www.mouser.be/ProductDetail/Bourns/CR0603-JW-102ELF?qs=rcPhh2wube3o3zlmFZCUPg%3D%3D
R2 | CR0603-JW-332ELF | 1 | https://www.mouser.be/ProductDetail/Bourns/CR0603-JW-332ELF
R7,R8,R9,R10,R11 | CR0603-FX-5101ELF | 5 | https://www.mouser.be/ProductDetail/Bourns/CR0603-FX-5101ELF?qs=sGAEpiMZZMtlubZbdhIBIMinHFTiNSf6ytasqlOqOko%3D
R4 | CR0603-JW-103ELF | 1 | https://www.mouser.be/ProductDetail/Bourns/CR0603-JW-103ELF?qs=tprK%2FdUq6q6vORSl%252Bpo4rg%3D%3D
R5 | CR0603-FX-2212ELF | 1 | https://www.mouser.be/ProductDetail/Bourns/CR0603-FX-2212ELF?qs=zx2075yZkZJFzojWSdyX6Q%3D%3D
R6 | CR0603-FX-4752ELF | 1 | https://www.mouser.be/ProductDetail/Bourns/CR0603-FX-4752ELF?qs=CCIlxZRRv7hsbWXGq3hzLw%3D%3D
SW1 | PTS815 SJM 250 SMTR LFS | 1 | https://www.mouser.be/ProductDetail/CK/PTS815-SJM-250-SMTR-LFS?qs=ahcBuItHZ3xKWmfV%2F2E6bA%3D%3D
U5 | BME680 | 1 | https://www.mouser.be/ProductDetail/Bosch-Sensortec/BME680?qs=v271MhAjFHjo0yA%2FC4OnDQ%3D%3D
U7,U8 | BR24G512FVT-5AE2 | 2 | https://www.mouser.be/ProductDetail/ROHM-Semiconductor/BR24G512FVT-5AE2?qs=MyNHzdoqoQKczk86bx4V7w%3D%3D
U3 | CP2102N-A02-GQFN24 | 1 | https://www.mouser.be/ProductDetail/Silicon-Labs/CP2102N-A02-GQFN24?qs=u16ybLDytRYKabtL%2FE7DZA%3D%3D
U2 | 317990829 | 1 | https://www.mouser.be/ProductDetail/Seeed-Studio/317990687
U1 | MCP73123-22SI/MF | 1 | https://www.mouser.be/ProductDetail/Microchip-Technology-Atmel/MCP73123-22SI-MF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
U6 | TSL25911FN | 1 | https://www.mouser.be/ProductDetail/ams-OSRAM/TSL25911FN?qs=6irNfxKJ9AaiNMbaQmyIug%3D%3D
U4 | GDEH0154D67 | 1 | https://www.mouser.be/ProductDetail/Mikroe/MIKROE-3157?qs=qSfuJ%252Bfl%2Fd4RQwi5AqGb6w%3D%3D

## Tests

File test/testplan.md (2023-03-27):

# Hardware Tests Before Flashing Firmware

So you've assembled a MuMo v2 PCB and now you want to test it to verify if the hardware was manufactured without errors.
Here is a step-by-step plan to do that:

1. Check for shorts between GND and 5V : use a multimeter to measure resistance between testpads for GND and 5V. You should NOT measure a low value (< 100 ohm). If not, check the soldering of the USB connector.
2. Check for shorts between GND and 3.3V : use a multimeter to measure resistance between testpads for GND and 3.3V. You should NOT measure a low value (< 100 ohm).

If there are no shorts in this part of the power supply, it should be safe to power a board via the USB connector.

3. Connect USB cable and plug the other side into a power usb port. Check for 5V and 3.6V presence on the test-pads

If this is OK, it should be safe to connect a battery

4. Unplug USB, and connect a battery. Double check the polarity of the battery, as the board is not designed to protect against wrong battery polarity !
5. Check presence of battery voltage on GND / 3V3 testpads
6. Additionally you can chech the current consumption from the battery. It should be around a few mA (this is the power consumption of the STM32WLE. The Wio-E5 module is factory programmed with an AT-Modem application)
6. ReConnect USB. Now you should measure the charging current of the LiFePO4 battery, which is around 150 mA

7. Now we are ready to flash some HW test software into the STM32WLE: 
    7.1 Connect the ST-Link programmer to the debug port. Either solder headers on the PCB (for prototyping) or use POGO pins (for volume production)
    7.2 The programmer needs the following 4 signals : GND, 3.3V, SWCLK, SWD.  SWO-Trace is provided on the connector (pin 5) but is not required for programming, only required for debug output during SW development. Check the correct order of the signals between the programmer and the MuMo board
    7.3 The Wio-E5 module gets a firmware programmed (an AT-Modem application). For some (mystery / license / ??) reason, after getting this firmware the STM32WLE is protected for reading out the firmware using the so-called option bits. In order to overwrite the already programmed application with our test-formware, you need to proceed as follows :
        7.4 : start the STM32CubeProgrammer
        7.5 : Press the RESET button on the MuMo board and while this button is pressed, click on Connect in the STM32CubeProgrammer. Now the programmer should find the bootloader of the SMT32WLE
        7.6 : Now remove the protection set by the OPTION bits : TBC
        7.7 : Now we can program our own application : select the .bin file, and program it.

# Hardware Tests from the Firmware

Now the firmware can perform a test-program :
1. The output of the tests will be sent to a serial-port over the USB, so on your PC, open a Serial Monitor program, set it to 115200 Baud. Reset the MuMo (reset button) and monitor the output to the serial port. You should see a welcome message and a prompt from the Command Line Interface (CLI)

2. Following commands are related to testing the board :
    2.1 : VER (VERsion) : will show information of the software version
    2.2 : TEST : run a complete hardware test displaying the results in the serial monitor

    This includes following tests :
    * Measure battery voltage
    * Detect all devices connected to I2C : show the addresses where devices are found :
    * Read / Write test of the EEPROM
    * Display test
    * UART loopback test when a jumper cable is connected between GROVE UART

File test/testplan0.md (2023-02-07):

# TestPlan

## Naked PCB
OK 1. check for short between GND, VBAT, 5V
2. check for continuity between
	- CP2102N and STM32 : Rx, Tx
	- USB 5V and MCP73123
	- STM32 and eInk connector : MOSI, SPICLK, CS, BUSY, D/C, e.a.

## Soldering
1. USB-C connector, 2 resistors, esd : test 5V
2. MCP73123 + passives : test battery charging
3. MCU + passives + BGR24G256 : test SWD, I2C, GPIO
4. eInk power supply + connector + passives : test display

## Assembled PCB - Front Only
### HW only tests
1. check for short between GND, VBAT
2. check if USB Serial is detected by PC
3. check if battery is being charged

### HW tests requiring firmware
4. send serial data
5. check if STM32 detects USB power
6. check if STM32 detects batteryVoltage
7. check if I2C devices are detected : 
	Grove BME680 = 0x76,
	Grove TSL2591 = 0x29,
	BR24G256 = 0x50
8. perform write / read test to BR24G256
9. detect RESET button being pressed
10. test serial connection over USB

## Assembled PCB - Front & Back
1. check if I2C devices are detected : onboard BME680 = 0x76, onboard TSL2591 = 0x29

## Assembly Log
1. the 4u7 caps are easily thombstoning.. How will they behave in reflow oven ?
2. SMA connector - check it's straight before soldering all grounds
3. first time flashing the SW : SWD is not enabled, so you need to keep reset pressed, then connect the ST-Link, then release reset. Then erase the BB bits into AA, then flash with firmware having SWD enabled.
4. 10K ? Is correct according to datasheet from mouser

## ToDo
1. Terminals on second battery
2. Ground pin on scope probe
3. Check continuity of all display signals
4. Fix display reset signal
5. check is wakeUp is possible from USB power on current pin, or if PA0 would be a better pin
6. check if SPI chip select can move to PB9
7. check if PB14 is available for BUSY input

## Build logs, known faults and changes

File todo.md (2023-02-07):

# Improvements for V2.1

1. provide solder pad to disable battery charger when eg using AA Alkaline cells. SW should somehow be able to know this
2. maybe use different SMA connector so antenna comes more into the center of the enclosure. Now it comes quite close to the front. To be assessed with actual antennas
6. should antenna connector be in the SMD stencil ? I think it will be hand-soldered
9. move writeProtect (PA0) to another pin, as this pin has wakeup capabilities ? Maybe it's more suited to wakeUp on USB power - check in firmware
10. fix stencil for SMA connector

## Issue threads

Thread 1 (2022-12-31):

GCT4085 USB connector is causing troubles in production

Strooom, 2022-12-31:
Two problems:
1. the pins are not long enough to go through a standard 1.55mm thick PCB
2. the spacings are smaller than the regular Class 6 PCB design rules, causing the PCB to be more expensive.

Will investigate to replace it with another, hopefully easier to use connector.

Closed 2022-12-31.

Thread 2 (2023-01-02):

rename KiCad project library

Strooom, 2023-01-02:
Current name : MuMo-v2-Node
As the repository already has a name, see if the project folder can be renamed to 'kicad_project'

Strooom, 2023-05-04:
done

Closed 2023-05-04.

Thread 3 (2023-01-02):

store files for project-specific library inside kicad project folder

Strooom, 2023-01-02:
* move from C:\Users\pasca\Documents\Projects\UA\MuMo-v2-Node-PCB\libraries
* to C:\Users\pasca\Documents\Projects\UA\MuMo-v2-Node-PCB\kicad_project\libraries

check if references to these files need to be changed in symbols, footprints and 3d models

Strooom, 2023-05-04:
done

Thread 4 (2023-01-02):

Improve D-/D+ trace properties

Strooom, 2023-01-02:
The D+/D- differential pair is not impedance-controlled. The recommendation is a minimal clearance of 0.127 mm (at JLCPCB without a
negative price impact). The trace width is about 0.8 mm. The pair is short, so this can be omitted

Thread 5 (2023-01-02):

Add stictching VIAs

Strooom, 2023-01-02:

Strooom, 2023-01-02:
added GND vias along the HF trace, and in all 'corners' of GND planes.
Several THT components also have a GND pin, serving as a connection of both planes.

Closed 2023-01-02.

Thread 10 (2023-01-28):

Correct ePaper display reset

Strooom, 2023-01-28:
Currently the reset is connected to the MCU reset (and related button), but I learned that the display can only wake up from deepsleep through a HW reset, so this signal must be connected to a GPIO

Strooom, 2023-05-04:
done

Closed 2023-05-04.

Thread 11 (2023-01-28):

Add solder bridges to disable battery charging when using non chargeable cells..

Strooom, 2023-01-28:
Imagine connecting 2 1.5 Alkaline AA cells. We should not try to charge those. A solder bridge which can be easily cut supports this scenario.

Strooom, 2023-05-04:
done

Closed 2023-05-04.

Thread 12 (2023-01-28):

Extend debug port connector with extra signals

Strooom, 2023-01-28:
Seems the ST-Link V3 needs a few extra signals, so in order to connect it easily, we should add:
* VCC (for voltage level detection by the debug probe)
* TRACESWO - (see also issue #7)
* Rx Tx for UART

Strooom, 2023-05-04:
done :
VCC and TRACESWO are now on the 5-pin debug connector.
RxTx are available on the GROVE serial connector

Closed 2023-05-04.

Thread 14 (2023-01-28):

Swap UART1 and UART2 pins

Strooom, 2023-01-28:
Bootloading is possible from :
• USART1 on pins PA9 and PA10
• USART2 on pins PA2 and PA3
• SPI1 on pins PA4, PA5, PA6 and PA7
• SPI2S2 on pins PB12, PB13, PB14 and PB1

Currently, the UART1 is using PB6 and PB7 pins, because PA10 is needed for SPI2
Connecting PA2 and PA3 to the CP2102N (and then PB6 PB7 to the Grove connector) will (maybe) allow for bootloading over the USB/Serial

Note : there are still some questions on how to bootload over USB/Serial, as pin PB13 does NOT seem to be the BOOT0 pin...

Strooom, 2023-05-04:
done

Closed 2023-05-04.

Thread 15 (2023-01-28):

Adjust PCB width to center ePaper display

Strooom, 2023-01-28:
In the current design, the flex-PCB on the ePaper is a bit short to have the display nicely centered. Measure the bend radius and see how to get enough room for the cable + center the display.

Could benefit from a cutout, so the PCB cable does not extend beyond the PCB width

Strooom, 2023-05-04:
done

Closed 2023-05-04.

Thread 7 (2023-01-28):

Move PB3 to debug port for TRACESWO

Strooom, 2023-01-28:
PB3 is currently a free GPIO, but it is the only pin which can do Debug/SWV/TRACESWO so I should dedicate it to that function.

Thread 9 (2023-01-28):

Correct decoupling capacitors in BOM

Strooom, 2023-01-28:
sometimes the 100n and 4u7 are mixed up : closest to the device should be 100n, others should be 4u7
see C23 - C25

Closed 2023-05-04.

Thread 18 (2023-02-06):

check annular ring for USB THT pins

Strooom, 2023-02-06:

Strooom, 2023-05-04:
done - footprint for this USB connector has been improved in the schematic, but not in the library!

Closed 2023-05-04.

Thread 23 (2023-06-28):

Check if we can reduce power by powering them from a GPIO

Strooom, 2023-06-28:
instead of powering the sensors, memory and display permanently from VBAT, we could wire the to an MCU IO, so we can switch of power when the MCU is not using them..

First thing to do is to measure what is the actual power-consumption, to assess if it is worthwhile to investigate this.

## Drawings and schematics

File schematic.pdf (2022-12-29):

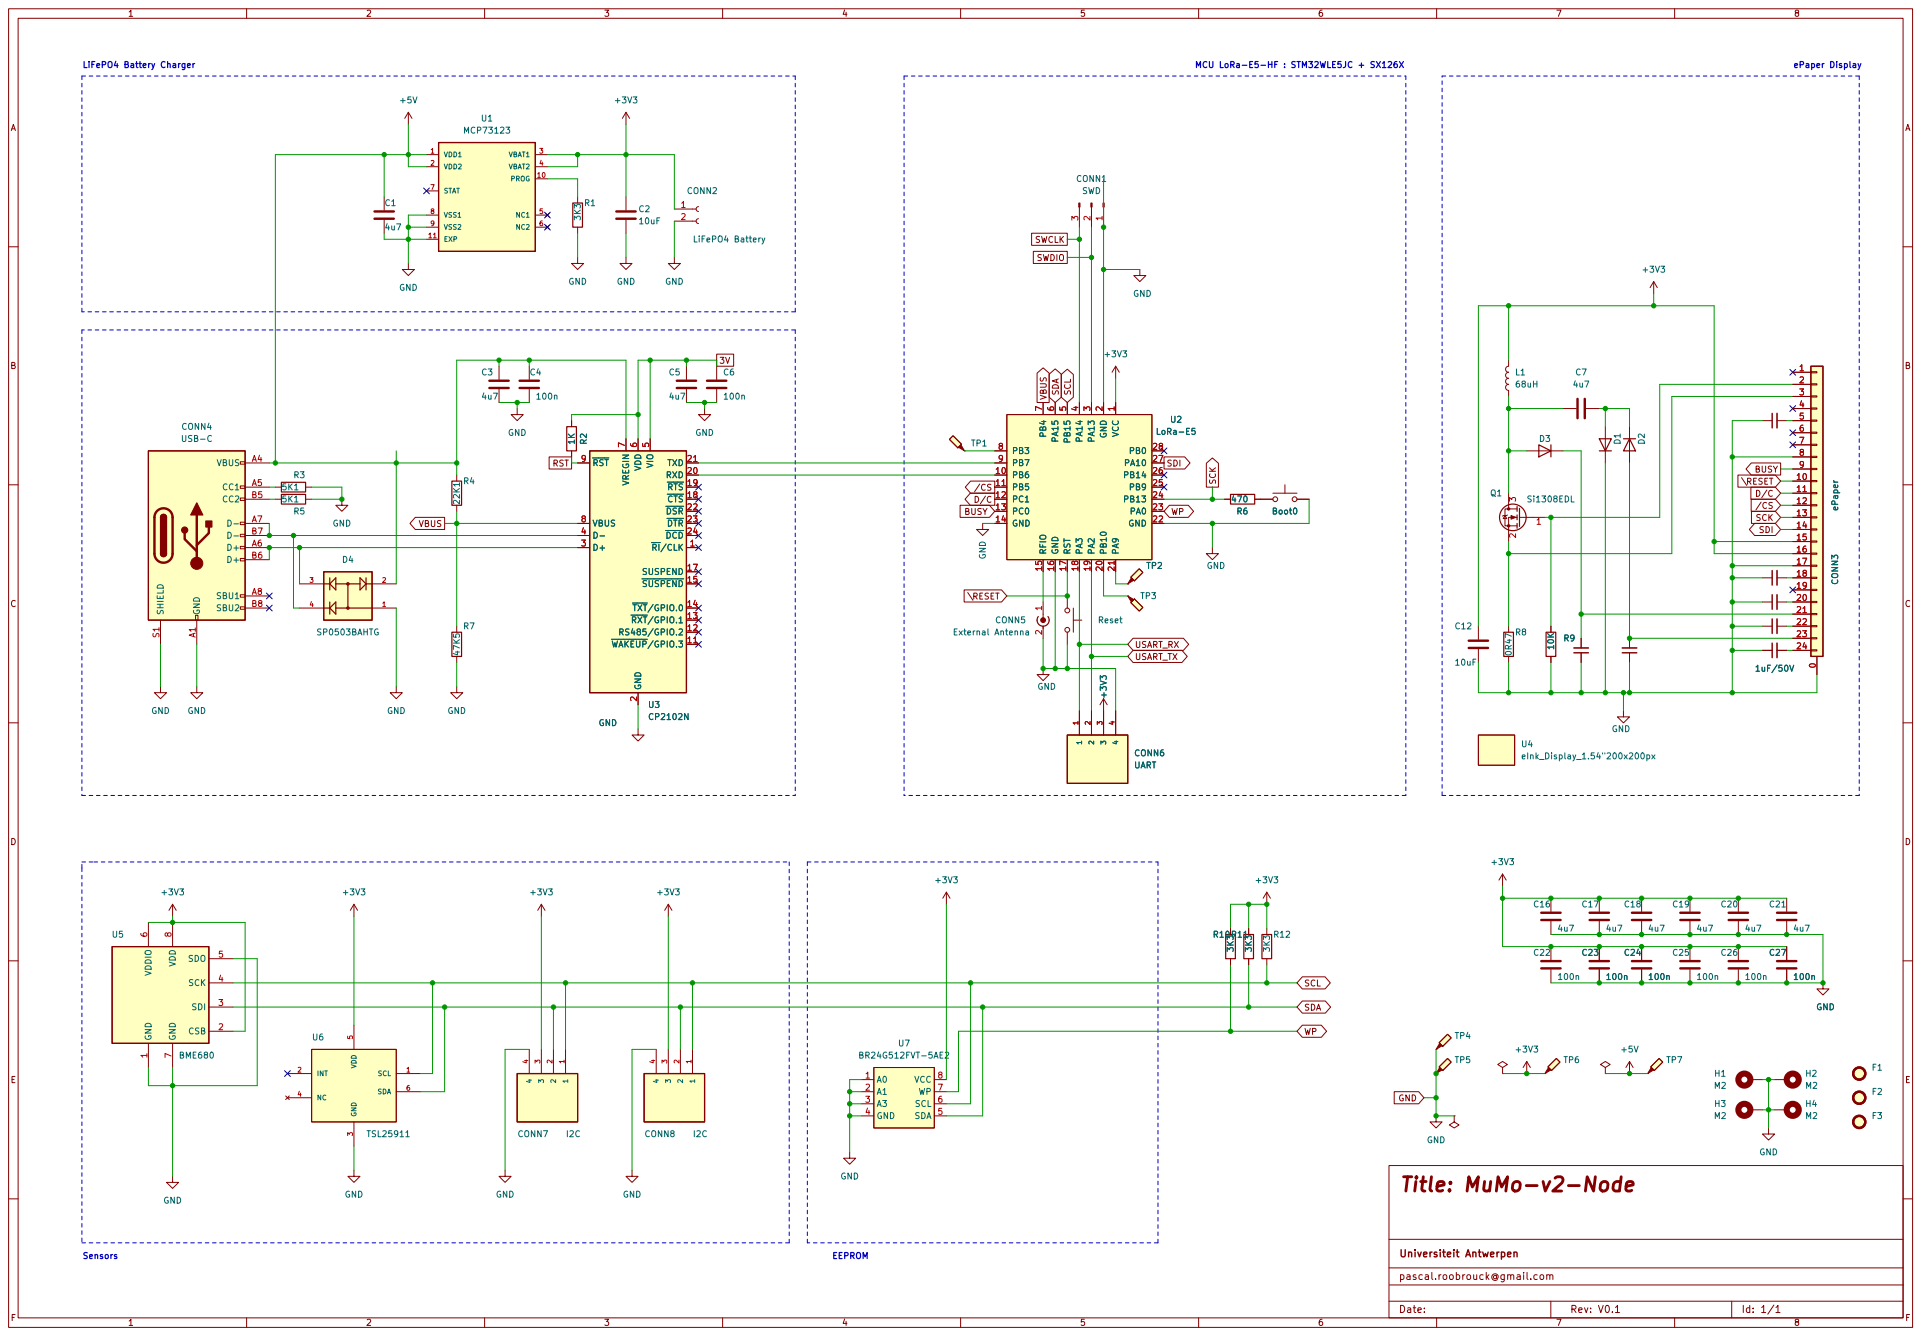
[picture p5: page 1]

3 3
4 4

1 PB6 10 PB5 11 PC1 12 PC0 13 GND 14 RFIO 15 GND 16 RST 17 PA3 18 PA2 19 GND

2 RXD 20 TXD 21 ~{DSR}22 ~{DTR}23 ~{DCD}24 D+ 3 D- 4 VIO

1 CSB 2 SDI 3 SCK 4 SDO 5 VDDIO

pascal.roobrouck@gmail.com

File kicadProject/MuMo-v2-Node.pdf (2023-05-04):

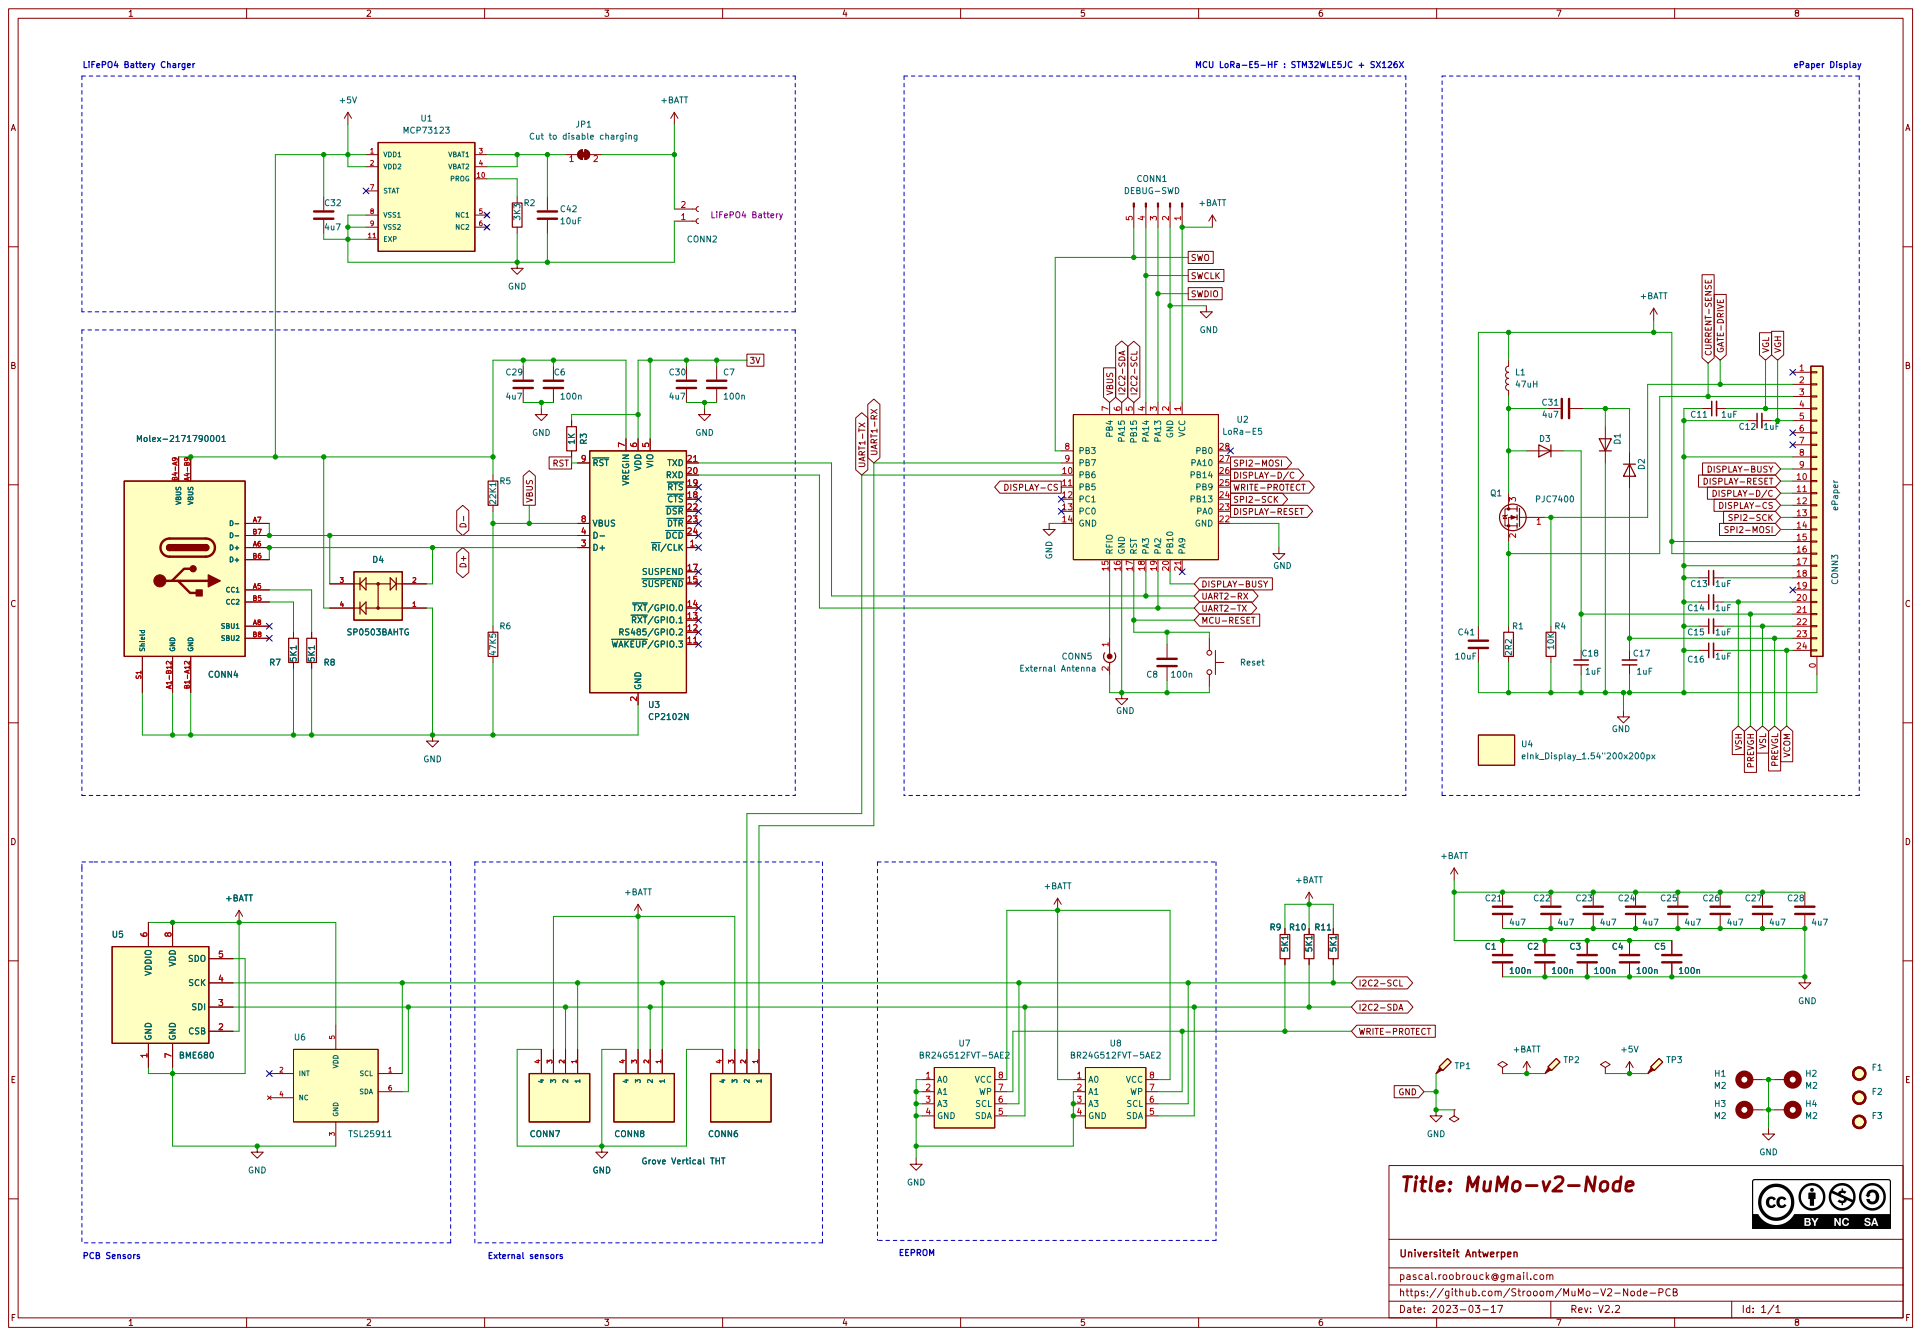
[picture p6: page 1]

JP1 Cut to disable charging C29

4 CONN6 A0 1 A1 2 A3 3 GND 4 SDA 5 SCL 6 WP 7 VCC 8 U7 BR24G512FVT-5AE2 +BATT I2C2-SDA

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

2 RXD 20 TXD 21 ~{DSR}22 ~{DTR}23 ~{DCD}24 D+ 3 D- 4 VIO

SPI2-MOSI DISPLAY-BUSY DISPLAY-RESET DISPLAY-CS UART2-RXDISPLAY-D/C

21
22
23

1 2 CONN5 External Antenna Reset GND

1 CSB 2 SDI 3 SCK 4 SDO 5 VDDIO

4 CONN7 Grove Vertical THT GND

pascal.roobrouck@gmail.com
https://github.com/Strooom/MuMo-V2-Node-PCB

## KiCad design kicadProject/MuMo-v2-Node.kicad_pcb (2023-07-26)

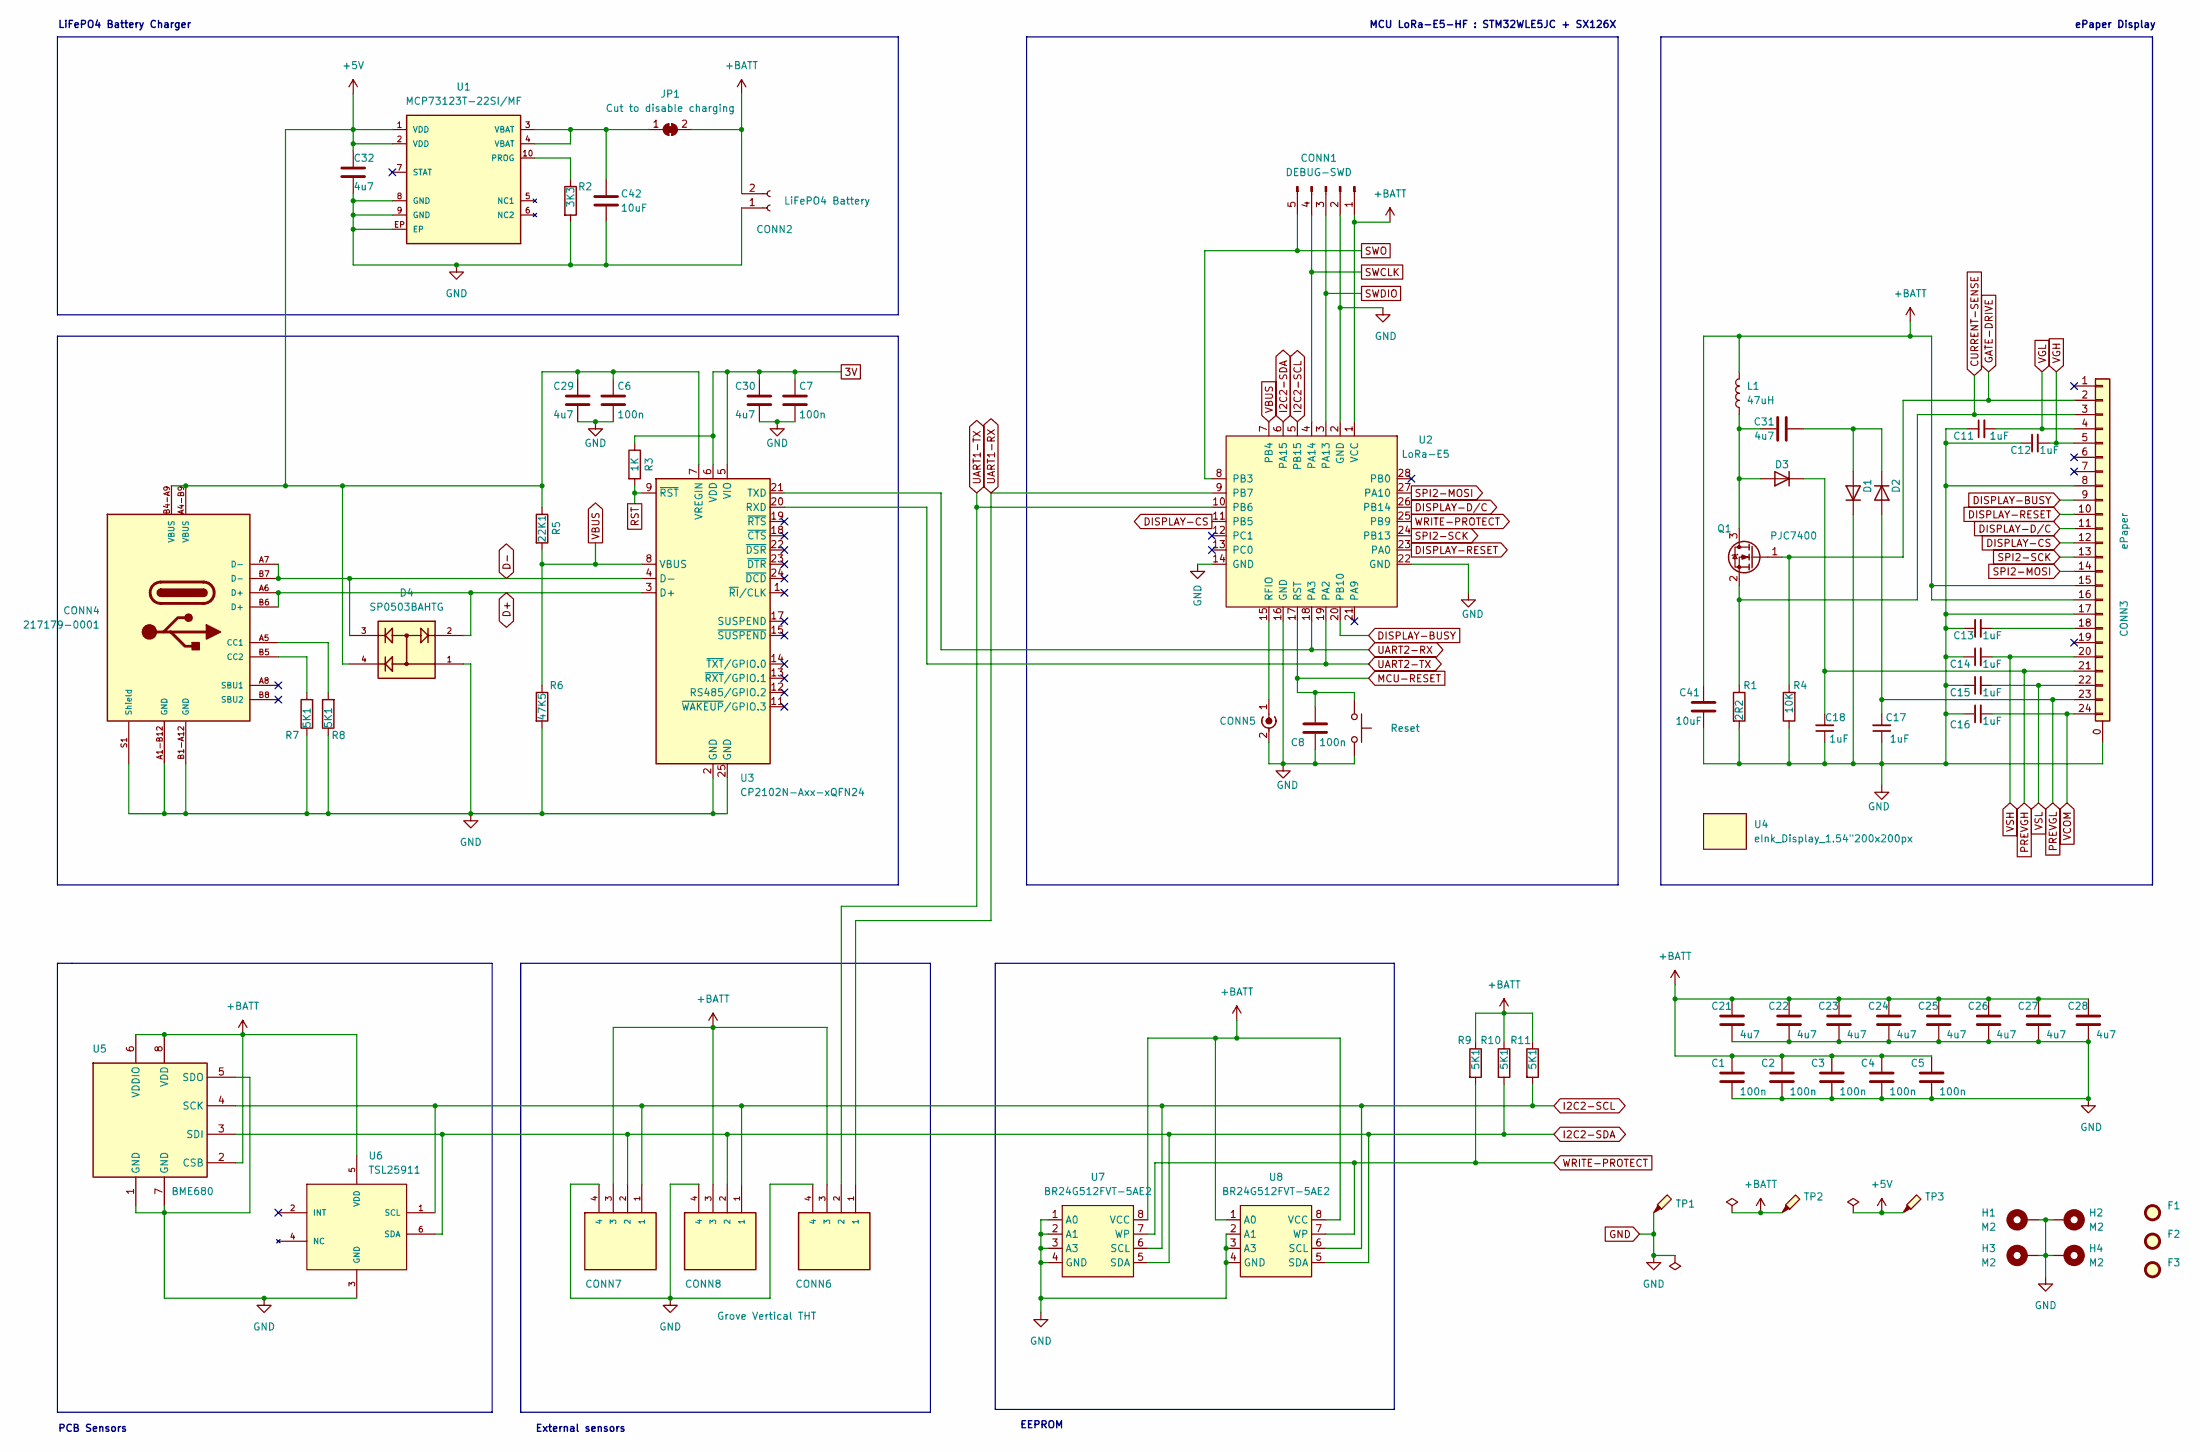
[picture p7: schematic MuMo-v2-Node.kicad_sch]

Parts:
C1, C2, C3, C4, C5, C6, C7, C8: 100n; 0603_1608Metric; MPN CGA3E2X7R1E104K080AA
C11, C12, C13, C14, C15, C16, C17, C18: 1uF; 0603_1608Metric; MPN CGA3E1X7R1E105K080AC
C21, C22, C23, C24, C25, C26, C27, C28, C29, C30, C31, C32: 4u7; 0603_1608Metric; MPN C1608X7S1A475K080AC
C41, C42: 10uF; 0603_1608Metric; MPN C1608X6S1A106M080AC
CONN1: DEBUG-SWD; PinHeader_1x05_P2.54mm_Vertical; MPN 10129378-905002BLF
CONN2: B2B-XH-A (LF)(SN); JST_XH_B2B-XH-A_1x02_P2.50mm_Vertical; MPN B2B-XH-A (LF)(SN)
CONN3: ePaper; TE_2-1734839-4_1x24-1MP_P0.5mm_Horizontal; MPN 2-1734839-4
CONN4: 217179-0001; Molex-2171790001; PARTREV A3
CONN5: Conn_Coaxial_Power; LINX_CONSMA020.062-G; MPN CONSMA020.062-G
CONN6, CONN7, CONN8: Grove Vertical THT; SEEED_110990030; MPN 110990030
D1, D2, D3: SS1FL3HM3/H; D_SMF; MPN SL03-GS08
D4: SP0503BAHTG; SP0503BAHTG-SOT143; PARTREV N/A
F1, F2, F3: Fiducial; Fiducial_0.75mm_Mask1.5mm; MPN notApplicable
H1, H2, H3, H4: M2; MountingHole_2.2mm_M2_Pad; MPN notApplicable
JP1: Cut to disable charging; SolderJumper-2_P1.3mm_Bridged2Bar_Pad1.0x1.5mm; MPN notApplicable
L1: 47uH; L_TDK_VLS6045EX; MPN VLS6045EX-470M
Q1: PJC7400; SOT-323_SC-70; MPN PJC7400_R1_00001
R1: 2R2; 0603_1608Metric; MPN ERJ-3RQJ2R2V
R2: 3K3; 0603_1608Metric; MPN CR0603-JW-332ELF
R3: 1K; 0603_1608Metric; MPN CR0603-JW-102ELF
R4: 10K; 0603_1608Metric; MPN CR0603-JW-103ELF
R5: 22K1; 0603_1608Metric; MPN CR0603-FX-2212ELF
R6: 47K5; 0603_1608Metric; MPN CR0603-FX-4752ELF
R7, R8, R9, R10, R11: 5K1; 0603_1608Metric; MPN CR0603-FX-5101ELF
SW1: Reset; SW_SPST_PTS815; MPN PTS815 SJM 250 SMTR LFS
TP1, TP2, TP3: testPad; TestPoint_THTPad_1.5x1.5mm_Drill0.7mm; MPN notApplicable
U1: MCP73123T-22SI/MF; DFN10 - MCP73123; MPN MCP73123T-22SI/MF
U2: LoRa-E5; MPN 317990687
U3: CP2102N-Axx-xQFN24; QFN24 - CP2102N; MPN CP2102N-A02-GQFN24R
U4: eInk_Display_1.54"200x200px; OSHW-Symbol_6.7x6mm_SilkScreen; MPN GDEH0154D67
U5: BME680; Bosch_BME680; MPN BME680
U6: TSL25911; TSL2591-SON; MPN TSL25911FN
U7, U8: BR24G512FVT-5AE2; TSSOP-B8; MPN BR24G512FVT-5AE2

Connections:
3V: C7.1, C30.1, R3.1, U3.5 (VIO), U3.6 (VDD)
+5V: C6.1, C29.1, C32.1, CONN4.A4-B9 (VBUS), CONN4.B4-A9 (VBUS), D4.4, R5.1, TP3.1, U1.1 (VDD), U1.2 (VDD), U3.7 (VREGIN)
+BATT: C1.1, C2.1, C3.1, C4.1, C5.1, C21.1, C22.1, C23.1, C24.1, C25.1, C26.1, C27.1, C28.1, C41.1, CONN1.1, CONN2.2 (+), CONN3.15, CONN3.16, CONN6.3, CONN7.3, CONN8.3, JP1.2 (B), L1.2, R9.1, R10.1, R11.1, TP2.1, U2.1 (VCC), U5.2 (CSB), U5.6 (VDDIO), U5.8 (VDD), U6.5 (VDD), U7.8 (VCC), U8.1 (A0), U8.8 (VCC)
CURRENT-SENSE: CONN3.3, Q1.2 (S), R1.1
D+: CONN4.A6 (D+), CONN4.B6 (D+), D4.2, U3.3 (D+)
D-: CONN4.A7 (D-), CONN4.B7 (D-), D4.3, U3.4 (D-)
DISPLAY-BUSY: CONN3.9, U2.20 (PB10)
DISPLAY-CS: CONN3.12, U2.11 (PB5)
DISPLAY-D/C: CONN3.11, U2.26 (PB14)
DISPLAY-RESET: CONN3.10, U2.23 (PA0)
GATE-DRIVE: CONN3.2, Q1.1 (G), R4.2
GND: C1.2, C2.2, C3.2, C4.2, C5.2, C6.2, C7.2, C8.2, C11.1, C12.1, C13.1, C14.1, C15.1, C16.1, C17.1, C18.1, C21.2, C22.2, C23.2, C24.2, C25.2, C26.2, C27.2, C28.2, C29.2, C30.2, C32.2, C41.2, C42.2, CONN1.2, CONN2.1 (-), CONN3.0 (GND), CONN3.8, CONN3.17, CONN4.A1-B12 (GND), CONN4.B1-A12 (GND), CONN4.S1 (Shield), CONN5.2 (Ext), CONN6.4, CONN7.4, CONN8.4, D1.1 (K), D4.1, H1.1, H2.1, H3.1, H4.1, R1.2, R2.2, R4.1, R6.2, R7.1, R8.1, SW1.1, TP1.1, U1.8 (GND), U1.9 (GND), U1.EP, U2.2 (GND), U2.14 (GND), U2.16 (GND), U2.22 (GND), U3.2 (GND), U3.25 (GND), U5.1 (GND), U5.5 (SDO), U5.7 (GND), U6.3 (GND), U7.1 (A0), U7.2 (A1), U7.3 (A3), U7.4 (GND), U8.2 (A1), U8.3 (A3), U8.4 (GND)
I2C2-SCL: CONN7.1, CONN8.1, R11.2, U2.5 (PB15), U5.4 (SCK), U6.1 (SCL), U7.6 (SCL), U8.6 (SCL)
I2C2-SDA: CONN7.2, CONN8.2, R10.2, U2.6 (PA15), U5.3 (SDI), U6.6 (SDA), U7.5 (SDA), U8.5 (SDA)
MCU-RESET: C8.1, SW1.2, U2.17 (RST)
unnamed: C13.2, CONN3.18
unnamed: CONN4.A5 (CC1), R8.2
unnamed: CONN4.B5 (CC2), R7.2
unnamed: CONN5.1 (In), U2.15 (RFIO)
unnamed: C31.1, D1.2 (A), D2.1 (K)
unnamed: C31.2, D3.2 (A), L1.1, Q1.3 (D)
unnamed: C42.1, JP1.1 (A), U1.3 (VBAT), U1.4 (VBAT)
unnamed: R2.1, U1.10 (PROG)
PREVGH: C18.2, CONN3.21, D3.1 (K)
PREVGL: C17.2, CONN3.23, D2.2 (A)
RST: R3.2, U3.9 (~RST)
SPI2-MOSI: CONN3.14, U2.27 (PA10)
SPI2-SCK: CONN3.13, U2.24 (PB13~)
SWCLK: CONN1.4, U2.4 (PA14)
SWDIO: CONN1.3, U2.3 (PA13)
SWO: CONN1.5, U2.8 (PB3)
UART1-RX: CONN6.1, U2.9 (PB7)
UART1-TX: CONN6.2, U2.10 (PB6)
UART2-RX: U2.18 (PA3), U3.21 (TXD)
UART2-TX: U2.19 (PA2), U3.20 (RXD)
VBUS: R5.2, R6.1, U2.7 (PB4), U3.8 (VBUS)
VCOM: C16.2, CONN3.24
VGH: C12.2, CONN3.5
VGL: C11.2, CONN3.4
VSH: C14.2, CONN3.20
VSL: C15.2, CONN3.22
WRITE-PROTECT: R9.2, U2.25 (PB9), U7.7 (WP), U8.7 (WP)

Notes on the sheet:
ePaper Display
LiFePO4 Battery Charger
EEPROM
External sensors
PCB Sensors
MCU LoRa-E5-HF : STM32WLE5JC + SX126X

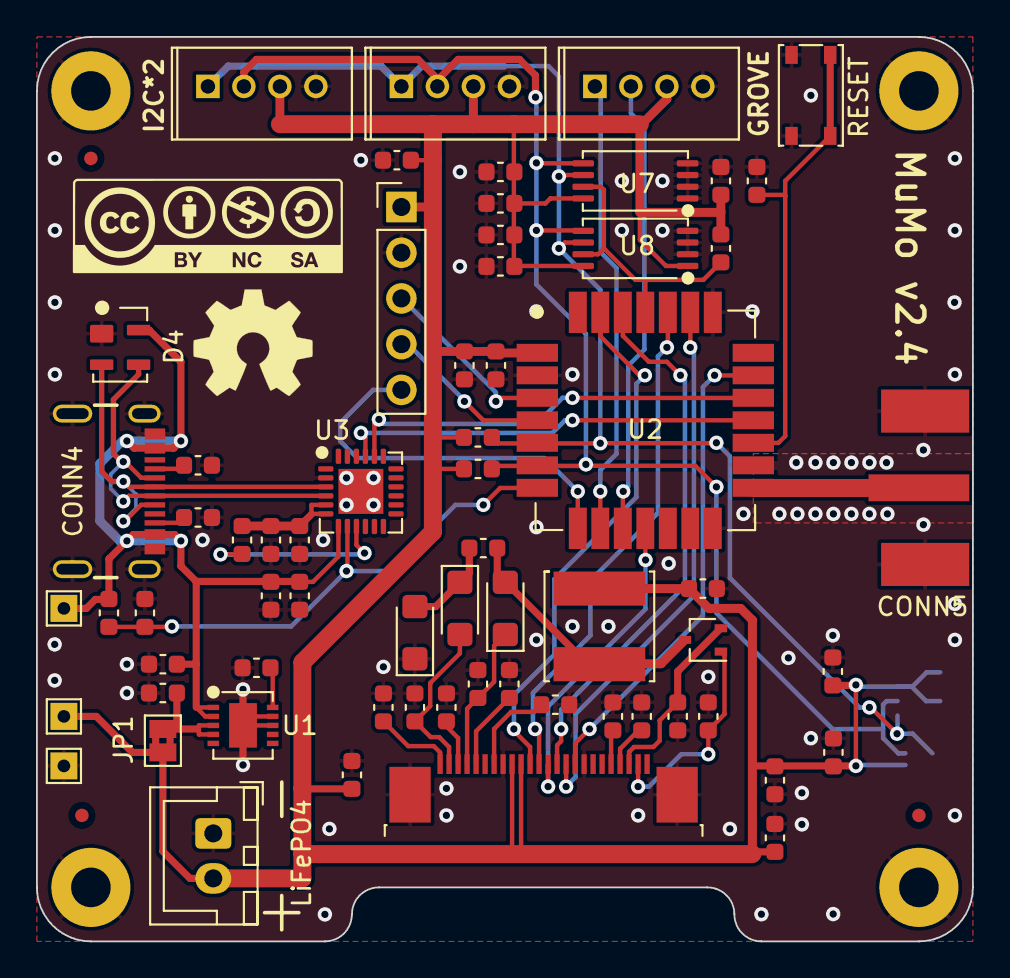
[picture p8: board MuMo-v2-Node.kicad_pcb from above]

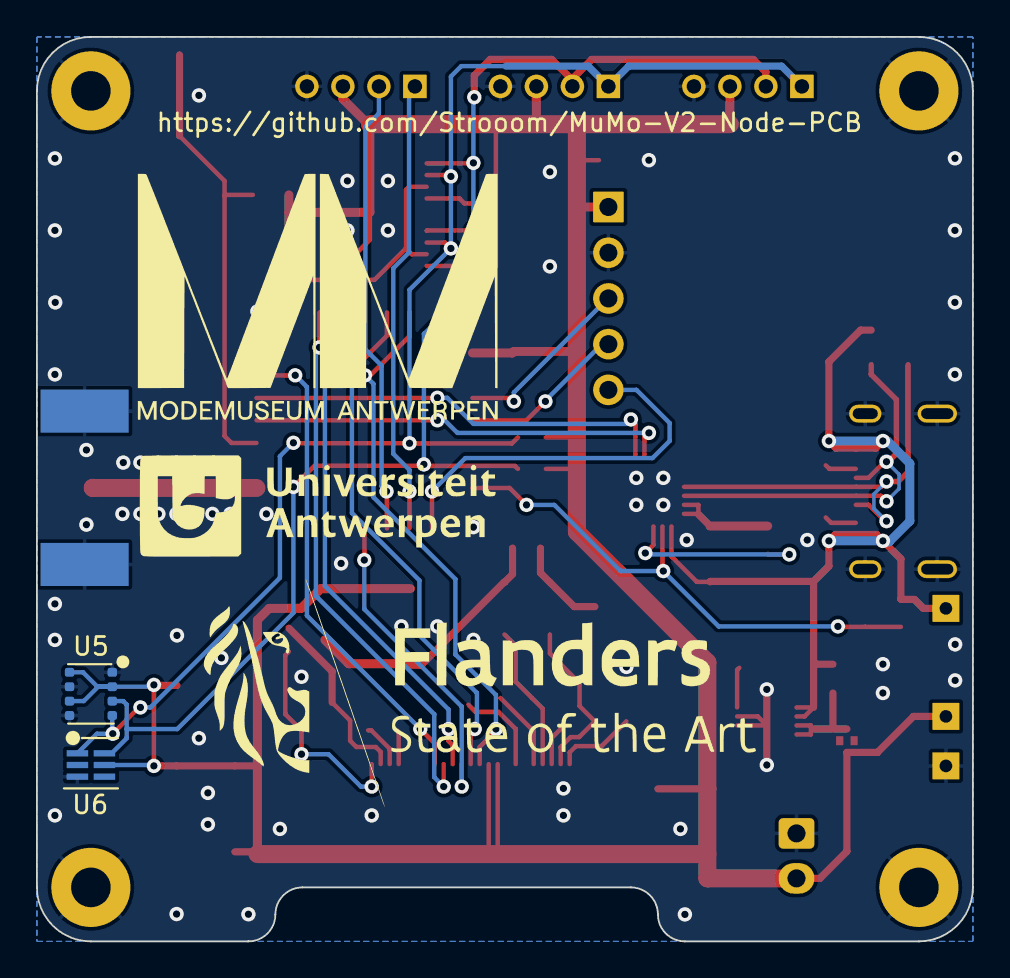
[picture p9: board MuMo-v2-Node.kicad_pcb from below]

Board: 2 copper layers, 52.0 x 50.3 mm, 75 parts (2 on the bottom side), 42 nets.

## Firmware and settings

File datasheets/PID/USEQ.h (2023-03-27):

// ************************************
// * USEQ -Header 
// ************************************
//#include <USEQ.h>
// USEQ.h
//
// Version 1.0 21-07-20
// 
// Standard datasets & commands for USEQ series I2C product
// Default Address for the USEQ device is 0x65h
// (Note ... is this shifted 1 bit to 11001010b / 202d / 0xCA)
//
//  There are 5 24-bit A-D's (Channels 00 - 04)
//  On single pixel USEQMS, the data comes in on Channel 2
//  On 2 x 2 pixel USEQMS, the data comes in on Channel 0-3
//
// Channel 0 is the Dark Pixel on the Sensor or the Temperature Sensor on the ASIC
// depending on the Configuration Setup
//
// USEQ i2c commands available
#define EP_TEST                 0x00
#define EP_VER                  0x02
#define EP_FIFO_STAT            0x04
#define EP_FIFO_RD_FULL         0x06
#define EP_FIFO_RD_ACTV         0x08
#define EP_FIFO_CLR             0x0A
#define EP_FIFO_RST             0x0C
#define EP_CCP_RD               0x0E
#define EP_CCP_WR               0x10
#define EP_AFE_RD               0x12
#define EP_AFE_WR               0x14
#define EP_WUP_RD               0x16
#define EP_WUP_WR               0x18
#define EP_ENG_RD               0x1A
#define EP_ENG_WR               0x1C
#define EP_ADDR_WR              0x1E
#define EP__SLEEP               0x20
#define EP_WAKE                 0x22
#define EP_RST_SFT              0x24
#define EP_RST_FULL             0x26
#define EP_MEMTST_ON            0x28
#define EP_MEMTST_OFF           0x2A
#define EP_MEMTST_WR_SAME       0x2C
#define EP_MEMTST_WR_ALT        0x2E
#define EP_MEMTST_RD            0x30

// I2C Error & State Flags
#define ERR_OK                  0
#define ERR_LON_DATA            1
#define ERR_NAK_ADDR            2
#define ERR_NAK_DATA            3
#define ERR_UNKNOWN             4
#define ON                      1
#define OFF                     0

// Data Set Package Definitions
#define EP_FIFO_SZ              17
#define EP_CCP_SZ               5
#define EP_AFE_SZ               2
//#define EP_WUP_SZ               6

#define EP_FIFO_CH0             0
#define EP_FIFO_CH1             3
#define EP_FIFO_CH2             6
#define EP_FIFO_CH3             9
#define EP_FIFO_CH4             12
#define EP_FIFO_FC              15

#define EP_OR_CH0               0x00
#define EP_OR_CH1               0x01
#define EP_OR_CH2               0x02
#define EP_OR_CH3               0x03
#define EP_OR_CH4               0x04

#define EP_OR_MSK               0x80  // Position of the OR flag for each channel

// Channel Control Packet
// **** Switch on Channel 2 only (Single Sensor) *****
#define EP_CCP_EN               0x01
#define EP_CCP_AMP_01X          0x0C
#define EP_CCP_AMP_02X          0x0A
#define EP_CCP_AMP_04X          0x08
#define EP_CCP_AMP_08X          0x06
#define EP_CCP_AMP_16X          0x04
#define EP_CCP_AMP_32X          0x02
#define EP_CCP_AMP_64X          0x00
#define EP_CCP_HP_FLTR1         0x00
#define EP_CCP_HP_FLTR2         0x10
#define EP_CCP_HP_FLTR4         0x20  
#define EP_CCP_HP_FLTR8         0x30
#define EP_CCP_TRNS_120T        0x00
#define EP_CCP_TRNS_060T        0x40  
#define EP_CCP_TRNS_030T        0x80  
#define EP_CCP_TRNS_015T        0xC0

#define EP_CCP_HPF_MSK         ~EP_CCP_HP_FLTR8
#define EP_CCP_TRNS_MSK       ~(EP_CCP_TRNS_060T| EP_CCP_TRNS_030T| EP_CCP_TRNS_015T)
#define EP_CCP_AMP_MSK         ~(EP_CCP_AMP_32X| EP_CCP_AMP_16X| EP_CCP_AMP_04X)
// Analog Front End Packet

#define EP_INT_EN               0x01
#define EP_TMP                  0x02
#define EP_SYN_SLV              0x04
#define EP_CLK_OUT_EN           0x08
#define EP_LOPASS_FRQ_090       0x10
#define EP_LOPASS_FRQ_045       0x20
#define EP_LOPASS_FRQ_022_5     0x30
#define EP_HIPASS_FLTR          0x40
#define EP_LO_POW               0x80

#define EP_LOPASS_MSK           ~(EP_LOPASS_FRQ_090| EP_LOPASS_FRQ_045|EP_LOPASS_FRQ_022_5)
#define EP_INT_DIS              0x00
#define EP_SYNC_MSTR            0x00
#define EP_CLK_OUT_DIS          0x00
#define EP_LOPASS_FRQ_180       0x00

// Define the I2C I/O pins
#define SDA_PORT                PORTD  
#define SDA_PIN                 4              // SDA = D4
#define SCL_PORT                PORTD          // SCL = D5
#define SCL_PIN                 5

// Define all the pin assignments for the Backplane Board
#define EP_LED_RUN              A0
#define EP_LED_RDY              A1
#define EP_CS1                  6
#define EP_CS2                  11
#define EP_CS3                  12
#define EP_CS4                  13
#define EP_INT1                 A4
#define EP_INT3                 A5
#define EP_INT4                 A6

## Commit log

2022-12-29 V0,1
    added all datasheets
    schematic complete
    PCB layout complete
    [1.54 E-ink assortment.cfg, 1.54in e-paper - Module.cfg, Asm4.cfg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]
2022-12-29 cleaned datasheets
    [1.54 E-ink assortment.cfg, 1.54in e-paper - Module.cfg, Asm4.cfg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]
2022-12-29 added GND vias
    [MuMo-v2-Node.kicad_pcb]
2022-12-29 Add images & pdfs
    [MuMo-v2-Node.csv, MuMo-v2-Node.kicad_pcb]
2022-12-30 update
    remove KiCAD backups from git repo
2022-12-31 fixed #1
    Replaced GCT4085 connector with Molex 2171790001
    [MuMo-v2-Node.kicad_pcb, MuMo-v2-Node.kicad_sch]
2023-01-03 Implemented improvements
    #5 stitching vias
    #4 USB differential pair
    #6 components / values for epaper driver circuit
    [MuMo-v2-Node.kicad_pcb, MuMo-v2-Node.kicad_sch]
2023-01-05 update project structure
    move the project libraries to a folder inside the KiCAD project
    [MuMo-v2-Node.csv, MuMo-v2-Node.kicad_pcb, MuMo-v2-Node.kicad_sch]
2023-01-05 uodate BOM with alternatives for 2 components that were out of stock
2023-02-07 V2.1
    Minor update, fixing issues #2 #3 #6 #7 #8 #9 #10 #11 #12 #13 #14 #15 #16 #17 #18 and #19
    [MuMo-v2-Node-B_Cu.gbr, MuMo-v2-Node-B_Mask.gbr, MuMo-v2-Node-B_Paste.gbr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]
2023-02-07 cleanup references
    sequential numbering for all identical parts
    [MuMo-v2-Node.kicad_pcb, MuMo-v2-Node.kicad_sch]
2023-02-08 cleanup old BOM files
    [MuMo-v2-Node_BOM.xlsx, MuMo-v2-Node_bom_V0.1.xlsx]
2023-02-08 added logo
    Flanders
    State of the Art
    [MuMo-v2-Node.kicad_pcb]
2023-02-20 Improving the BOM
    Grouped designators,
    Added logo to silkscreen
    [MuMo-v2-Node-B_Cu.gbr, MuMo-v2-Node-B_Mask.gbr, MuMo-v2-Node-B_Paste.gbr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]
2023-02-21 updated gerbers for Seeed Studio Manufacturing
    [MuMo-v2-Node-B_Cu.gbr, MuMo-v2-Node-B_Fab.gbr, MuMo-v2-Node-B_Mask.gbr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]
2023-03-17 corrected battery connector
    To align with most common premade cables, pin 1 = GND, pin 2 - VBAT
    [MuMo-v2-Node.kicad_pcb, MuMo-v2-Node.kicad_sch]
2023-07-26 V2.4
    Updated to Kicad V7
    * small design improvements, resolving the DRC of V7
    * ready for production at Aisler
    [MuMo-v2-Node.kicad_pcb, MuMo-v2-Node.kicad_sch]
2023-07-26 added polarity to pins of battery connector
    [MuMo-v2-Node.kicad_sch]
